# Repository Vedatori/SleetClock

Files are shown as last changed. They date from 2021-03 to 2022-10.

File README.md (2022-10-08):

# SleetClock [cz]
SleetClock je otevřená platforma chytré meteostanice vyvinutá jako projekt pro výuku elektroniky a programování. Ve fázi návrhu byl kladen důraz na jednoduchou a levnou výrobu s vysokou užitnou hodnotou výsledného výrobku v každé domácnosti.

SleetClock byl vyvinut jako hlavní výrobek letního technického tábora 2019 v Chotěborkách pořádaným spolkem Vědátoři.
Do vývojového týmu patří Martin Ptáček, Martin Coufal, Marek Coufal a Petr Vávra z Brna.

Meteostanice je založena na 3D tištěném a laserem vyřezávaném překližkovém šasi. Srdcem výrobku je vývojový kit ESP32, který se stará o vyčítání hodnot ze senzorů, bezdrátovou komunikaci, ovládání LED symbolů počasí a o vykreslování na grafické obrazovce.

SleetClock se vyznačuje:
* Nokia 84x48 LCD grafická orbrazovka
* ESP32 MCU s podporou WiFi & Bluetooth
* Integrovaný a externí teplotní senzor
* LED indikátor počasí
* Rotační ovládací prvek, potenciometr, tlačítka a dotykové ovládání

Chceš si sestavit vlastní SleetClock? Přesuň se do sekce [návody](Manuals) a postupuj v pořadí:
1. [Elektronika](Manuals/SleetClock_electronics_cz.md)
1. [Mechanika](Manuals/SleetClock_mechanics_cz.md)
1. [Dotykový senzor](Manuals/SleetClock_touchSensor_cz.md)

## Licence
* Obsah tohoto repozitáře mimo složku *Software* je sdílen pod licencí [Attribution-NonCommercial-ShareAlike 4.0 International (CC BY-NC-SA 4.0)](https://creativecommons.org/licenses/by-nc-sa/4.0/).
* Obsah složky *Software* je sdílen pod licencí [GNU Lesser General Public License v3.0](https://www.gnu.org/licenses/lgpl-3.0.en.html).

# SleetClock [en]
SleetClock is an open-source weather station platform developed as a support for electronics and programming education. In construction emhasis was placed on easy and low-cost fabrication with a broad utilization of final product in any household.

SleetClock was developed to be the main technical project in Chotěborky 2019 Summer Camp organised by the Vědátoři society.
The developer team includes Martin Ptacek, Martin Coufal, Marek Coufal & Petr Vavra from Brno, Czech Republic.

The meteostation is based on a semi 3D-printed and plywood laser cutted chassis. SleetClock is powered by the ESP32 MCU dev kit, which takes care of reading sensor data, wireless communication, controlling the LED weather symbols and the graphical display.

The main features of SleetClock include:
* Nokia 84x48 LCD graphical display
* ESP32 MCU that enables wireless communication via WiFi & Bluetooth
* On-board & external temperature sensor
* LED weather indicator
* Rotary encoder, potentiometer, buttons & touch user control

Ready to assemble your own SleetClock? All manuals use czech descriptions so we advice using the translated version of the site. Head to section [Manuals](Manuals) and proceed in order:
1. [Electronics](Manuals/SleetClock_electronics_cz.md)
1. [Mechanics](Manuals/SleetClock_mechanics_cz.md)
1. [Touch sensor](Manuals/SleetClock_touchSensor_cz.md)

## License
* The contents of this repository excluding folder *Software* is shared under license [Attribution-NonCommercial-ShareAlike 4.0 International (CC BY-NC-SA 4.0)](https://creativecommons.org/licenses/by-nc-sa/4.0/).
* The contents of the folder *Software* is shared under license [GNU Lesser General Public License v3.0](https://www.gnu.org/licenses/lgpl-3.0.en.html).

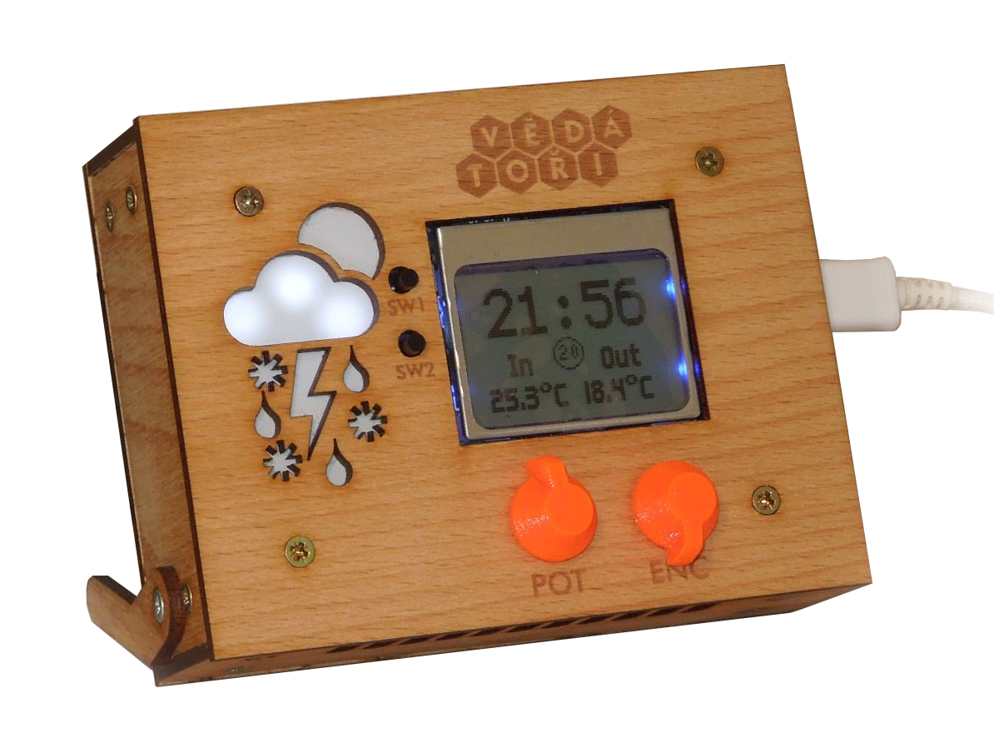
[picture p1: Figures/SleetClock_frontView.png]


Základní schéma zapojení / Schematic general:\
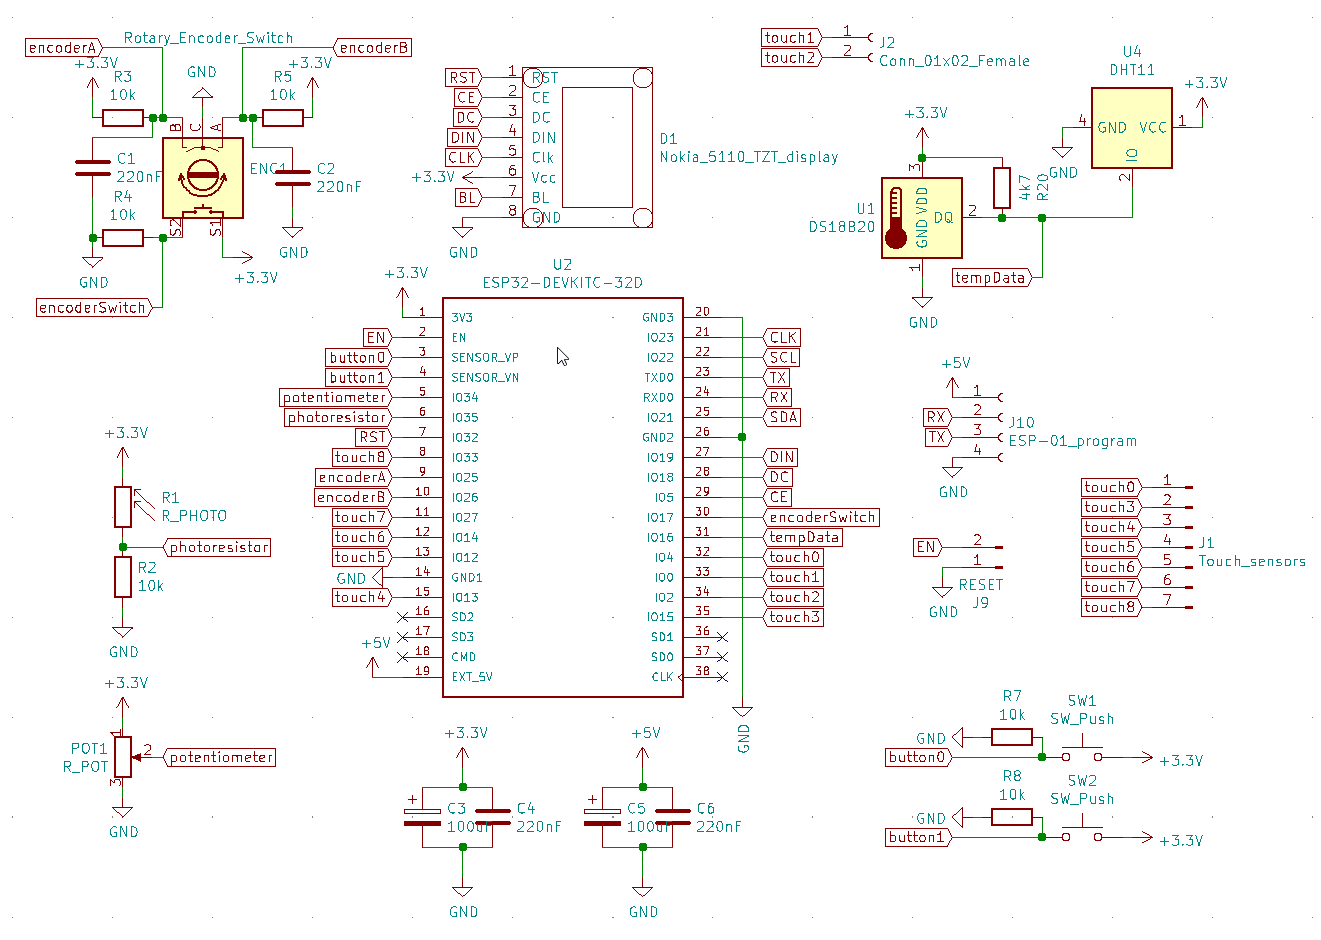
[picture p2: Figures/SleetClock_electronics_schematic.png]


Schéma zapojení LED PWM ovladače / Schematic LED PWM driver:\
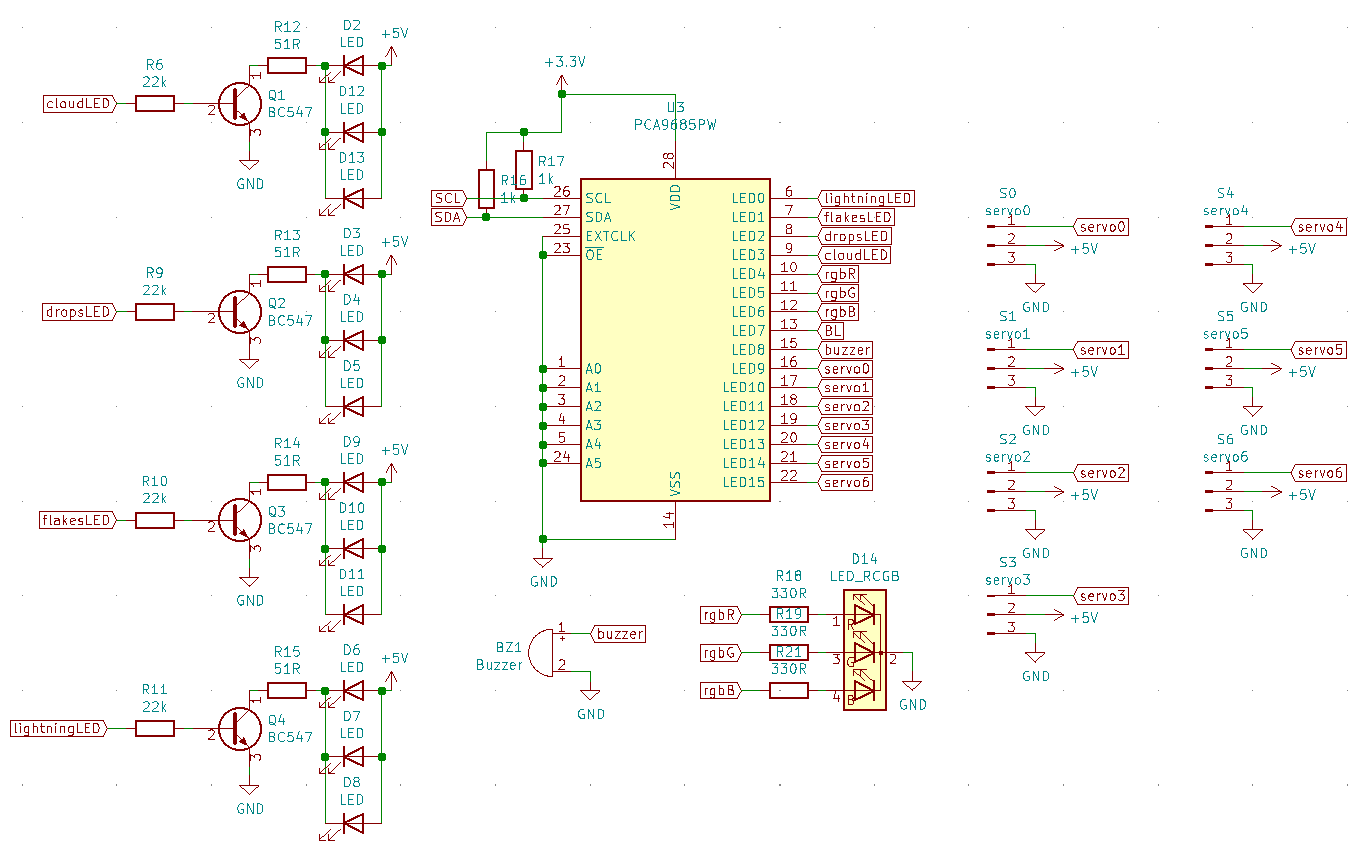
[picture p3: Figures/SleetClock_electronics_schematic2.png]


Navržená deska plošných spojů / Routed board:\
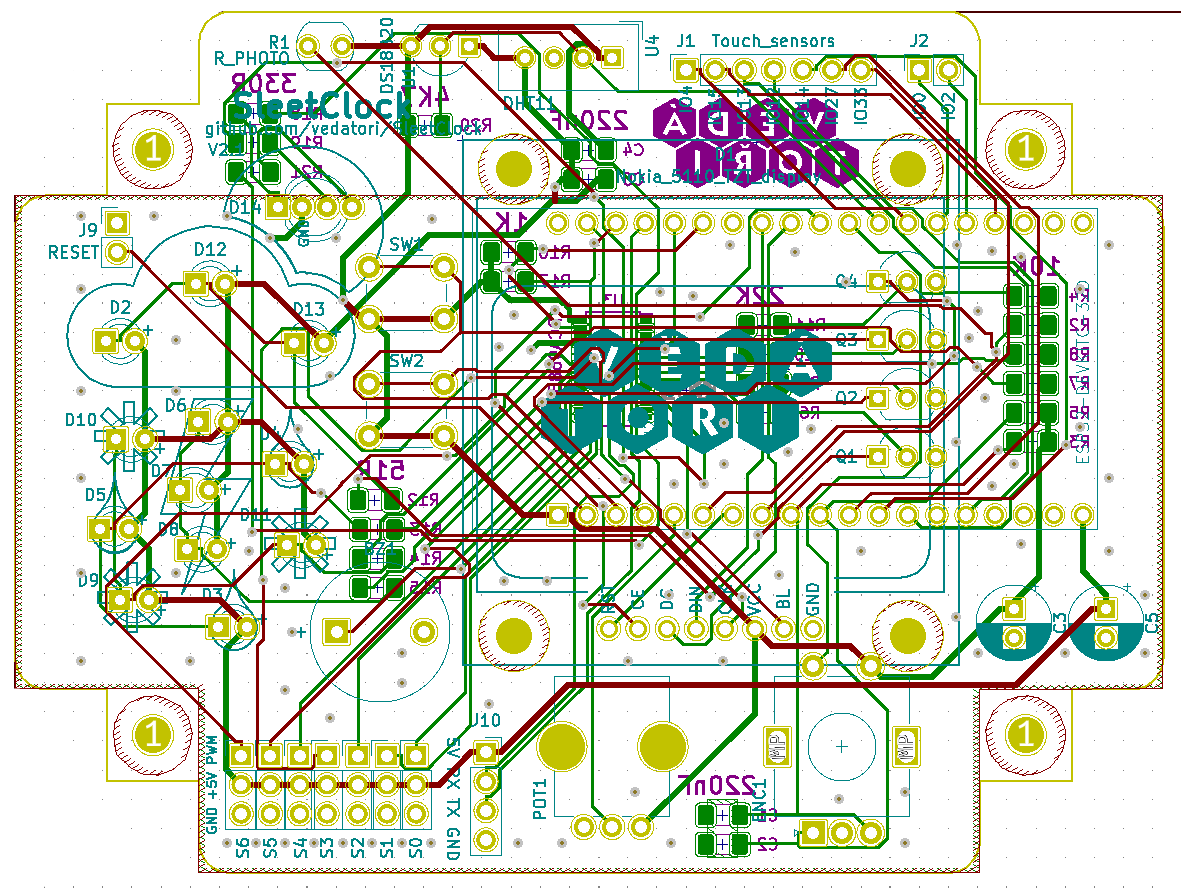
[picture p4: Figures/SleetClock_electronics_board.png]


Realizace PCB a vnitřní část šasi / Realization of PCB and inside the chassis:\
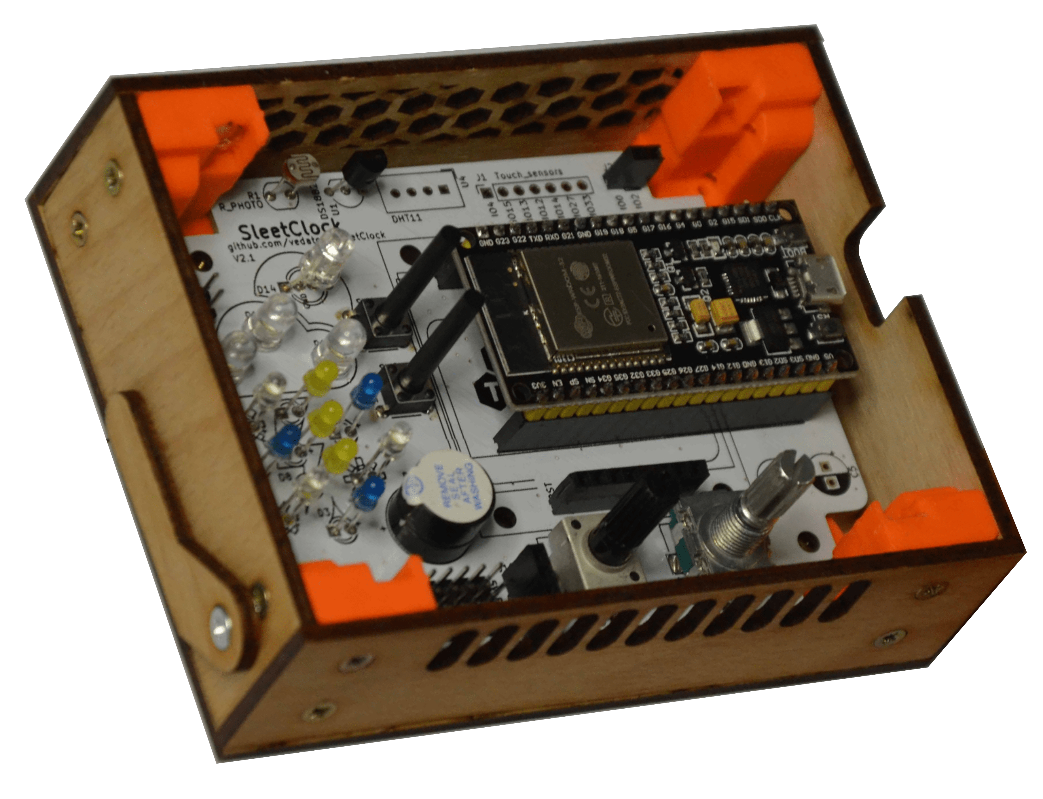
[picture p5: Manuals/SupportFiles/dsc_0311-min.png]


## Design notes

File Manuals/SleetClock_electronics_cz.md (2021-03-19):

V této kapitole je návod pro osazení desky plošných spojů pro SleetClock. V první části je osazována hlavní deska, v druhé části je popsáno osazení externího senzoru.
___
# Obsah
* [Seznam součástek](#seznamSleet)
* [Rozlomení PCB](#rozlomeni)
* [Zapájení SMD rezistorů](#smdR)
* [Zapájení SMD kondenzátorů](#smdC)
* [Zapájení kolíkových lišt](#kolik)
* [Zapájení dutinkových lišt](#dutinky)
* [Zapájení tranzistorů BC547A](#tranzistory)
* [Zapájení bzučáku](#bzucak)
* [Zapájení teplotního senzoru Dallas DS18B20](#dallas)
* [Zapájení fotorezistoru](#fotoR)
* [Zapájení 25mm tlačítek](#tlac)
* [Zapájení luminiscenčních diod (LED)](#LED)
* [Zapájení potenciometru a enkodéru](#potenc)
* [Dokončení vývojové desky](#finish)
___

## Seznam součástek
+ Vyfrézovaná PCB (Printed Circuit Board - deska plošných spojů)
+ PCA9685
+ SMD Rezistory vel. 1206 (před závorkou je uvedena hodnota, v závorce kódové označení na rezistoru)
    + 4x 51 Ω (510)
    + 3x 330 Ω (331)
    + 2x 1 KΩ (102)
    + 1x 4,7 KΩ (472)
    + 6x 10 KΩ (103)
    + 4x 22 KΩ (223)
+ 4x SMD kondenzátor 220 nF (bez popisku), vel. 1206
+ Teplotní senzor DS18B20
+ Fotorezistor
+ Kolíkové lišty
+ Dutinkové lišty
+ LED
    + RGB se společnou katodou (nejdelší nožička)
    + 3x 5 mm studená bílá
    + 3x 3 mm studená bílá
    + 3x 3 mm modrá
    + 3x 3 mm žlutá
+ Bzučák
+ 2x tlačítko 25 mm
+ 4x tranzistor BC547A
+ Potenciometr 10 KΩ s hřídelí 18mm
+ Rotační enkodér
+ ESP32 devkit
+ Nokia 5110 display
+ Jumper
+ 4x šroub M3x20 s půlkulatou hlavou
+ 8x matka M3
+ 3D tištěný tepelný štít

Součástky na zapájení do PCB můžete vidět na následujícím obrázku:
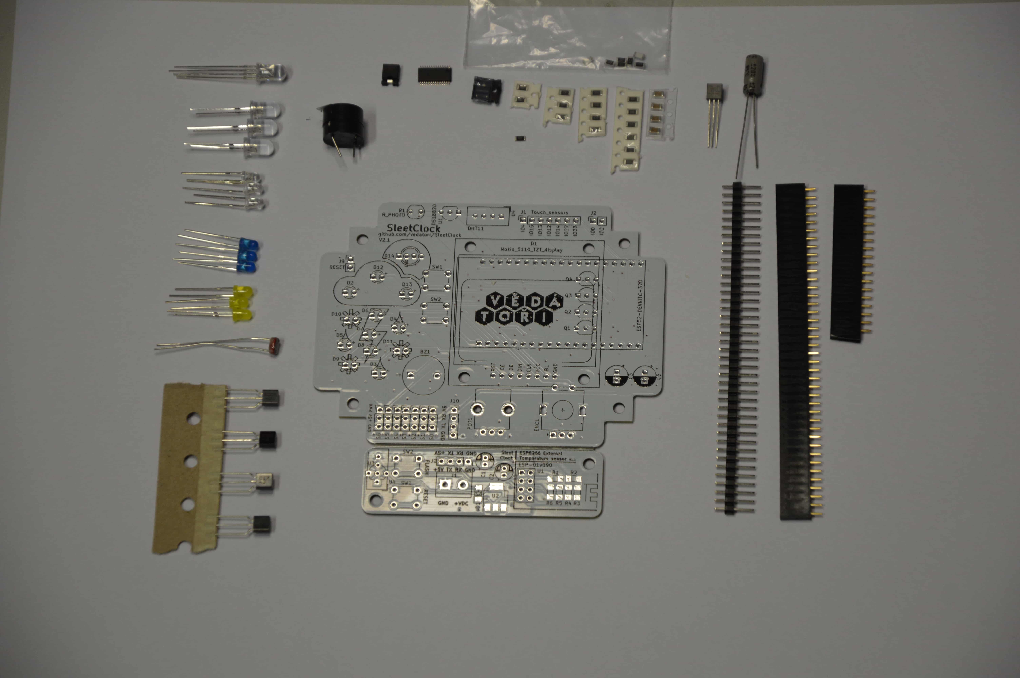
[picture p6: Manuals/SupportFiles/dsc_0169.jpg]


## Rozlomení PCB
1. Na jednom PCB je umístěna jak hlavní deska, tak i deska externího senzoru. PCB je frézovaná, rozlomte ho na dvě části podle drážky. To by mělo jít bez použití nadměrné síly.

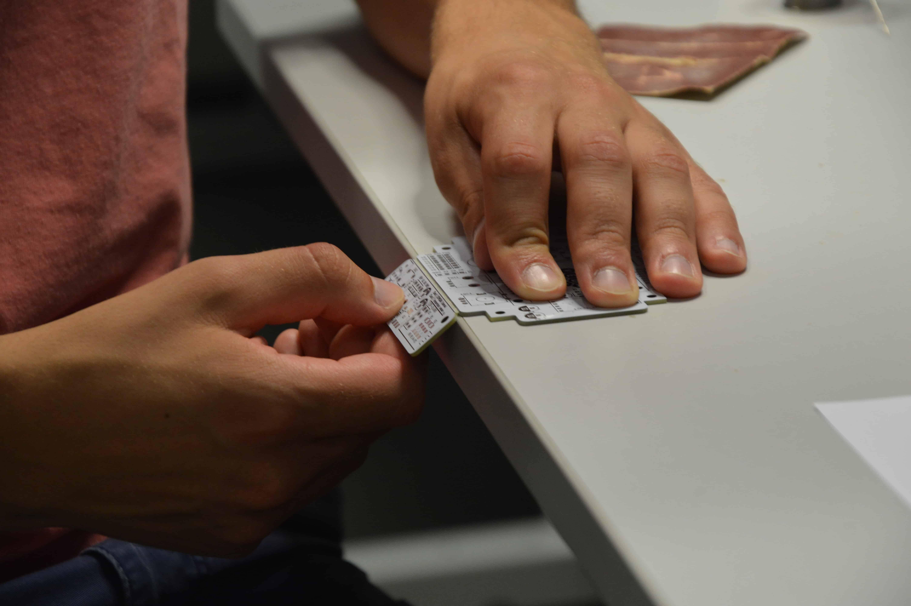
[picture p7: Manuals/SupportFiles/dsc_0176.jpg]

2. Po rozlomení opracujte nově vzniklé hrany smirkovým papírem.
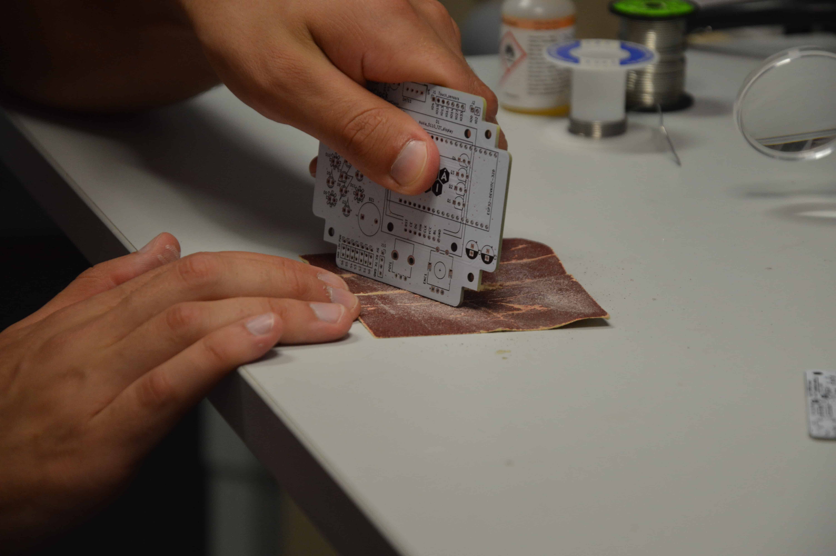
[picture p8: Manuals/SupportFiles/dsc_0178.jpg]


#### Pohled na hlavní PCB
Toto je pohled na PCB zepředu. Z této strany se SleetClock běžně nepájí! Existuje však jedna výjimka, ale o té se v návodu dočtete. :)
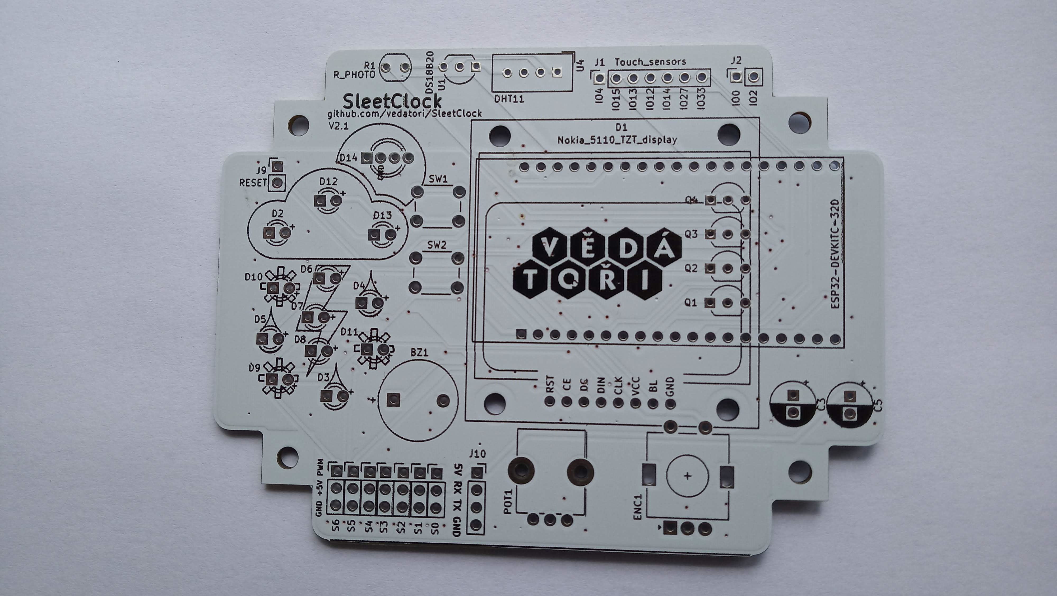
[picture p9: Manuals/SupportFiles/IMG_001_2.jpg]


Takto vypadá SleetClock zezadu. Z této strany budete pájet naprostou většinu součástek. Jako malý dárek už od nás máte zapájené PCA (integrovaný obvod SOIC). :) To má tak malé rozteče vývodů, že jsme pro něj zvolili jinou techniku pájení. Jen si zkontrolujte, že tam opravdu je.
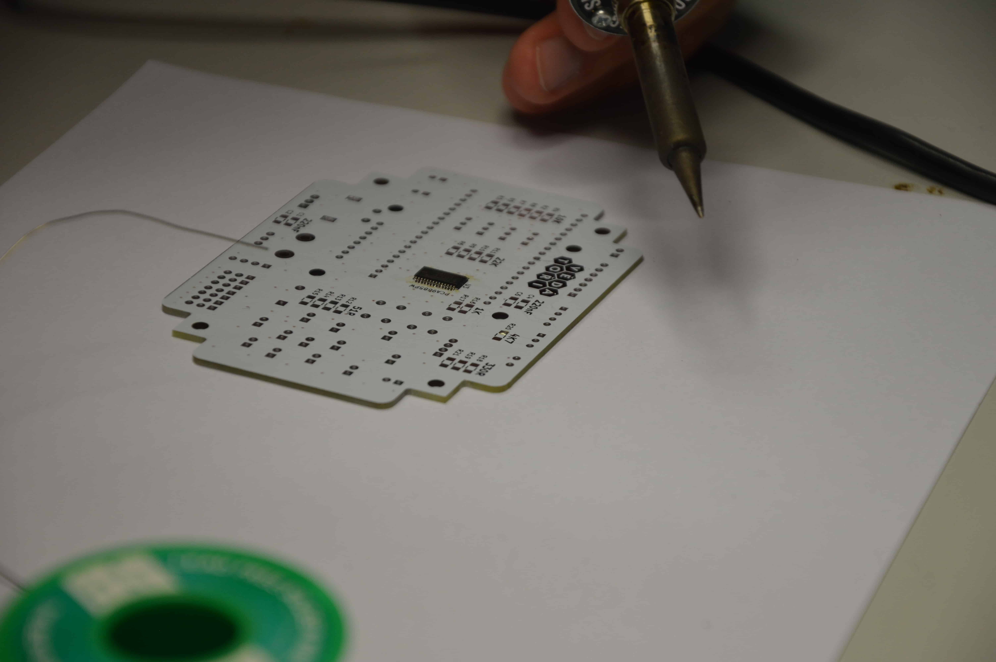
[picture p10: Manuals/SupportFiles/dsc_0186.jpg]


#### Osazení hlavní PCB
Součástky pajíme do PCB v pořadí podle 2 klíčů:
* Nejdříve nejmenší - ať neblokují místo při pájení dalších součástek
* Nejdříve teplotně nejodolnější - kdyby došlo k jejich nahřátí při dalším pájení
Tyto dvě metody nejdou vždy ruku v ruce, je tedy zvolen vhodný kompromis.

Následující součástky (SMD - Surface Mount Device) se na desku přikládají i pájí ze spodní strany (bez nápisu SleetClock).

## <a name = "smdR">Zapájení SMD rezistorů</a>
Nyní zapájejte SMD rezistory.
Jako první pájejte SMD rezistor hodnoty 4,7 KΩ. Je na něm napsáno “472”, což je myšleno jako 47*10^2. Takto jsou značeny všechny použité SMD rezistory. Tento rezistor zapájejte na místo s označením 4K7.
Nápisy na rezistorech musí směřovat nahoru, aby zůstaly čitelné. Stejně tak nesmí být nápis na rezistoru “vzhůru nohama”.    
1. Nahřejte jednu plošku pro SMD rezistor a přidejte na ni malé množství cínu.
1. Pinzetou uchopte rezistor a přiložte ho na cín, který se uchytil na plošce. Dbejte na jeho správné usazení, nesmí být posunutý a nesmí stát ve vzduchu.\  
1. Cín nahřejte páječkou. Pinzetou dolaďte umistění rezistoru, když je cín roztavený.
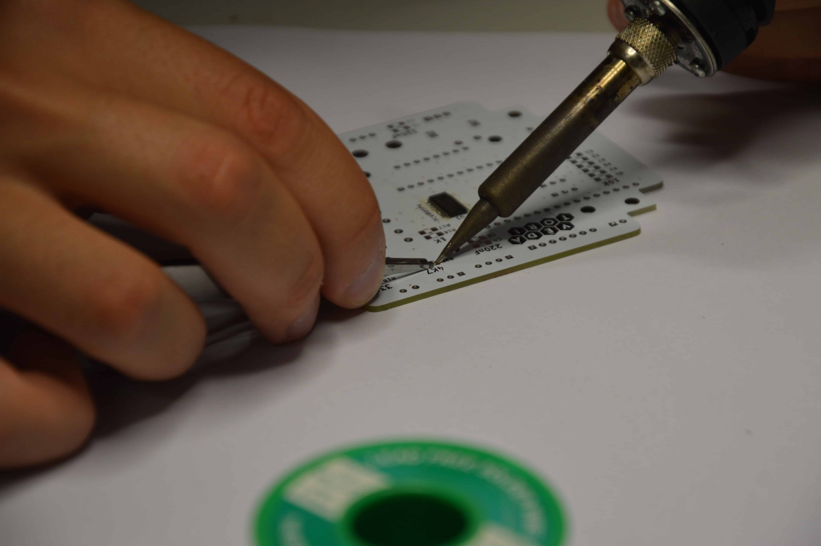
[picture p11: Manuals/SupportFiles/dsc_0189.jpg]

1. Zapájejte druhý vývod rezistoru. Nahřejte vývod a plošku a poté přidejte malé množství cínu potřebné k jejich spojení.\
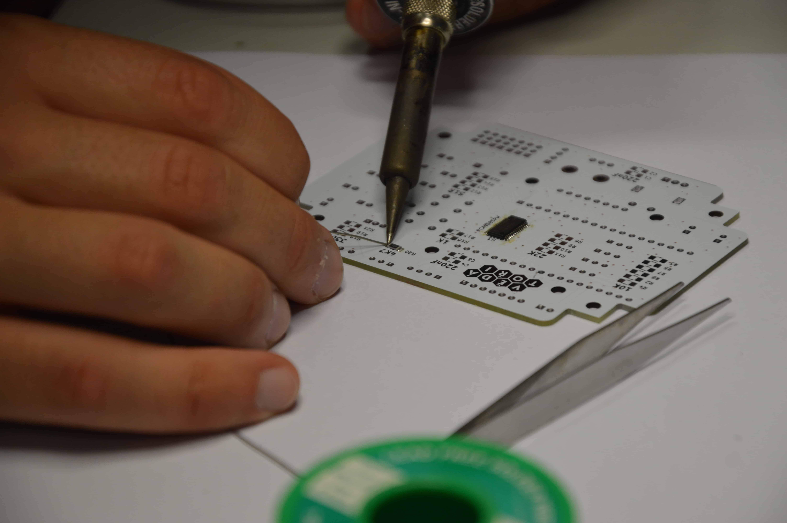
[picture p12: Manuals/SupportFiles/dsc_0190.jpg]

1. Obdobným způsobem zapájejte ostatní rezistory. Na polích s více rezistory si vždy naneste cín na všechny plošky na jedné straně a poté po jednom pinzetou přikládejte rezistory. Ty musí být vpájeny do správných míst podle popisků na plošném spoji podle následujícího rozpisu (před závorkou je uvedené označení na desce a v závorce kód rezistoru):
    + 4x 51R (510)
    + 3x 330R (331)
    + 2x 1K (102)
    + 1x 4K7 (472)
    + 6x 10K (103)
    + 4x 22K (2202)
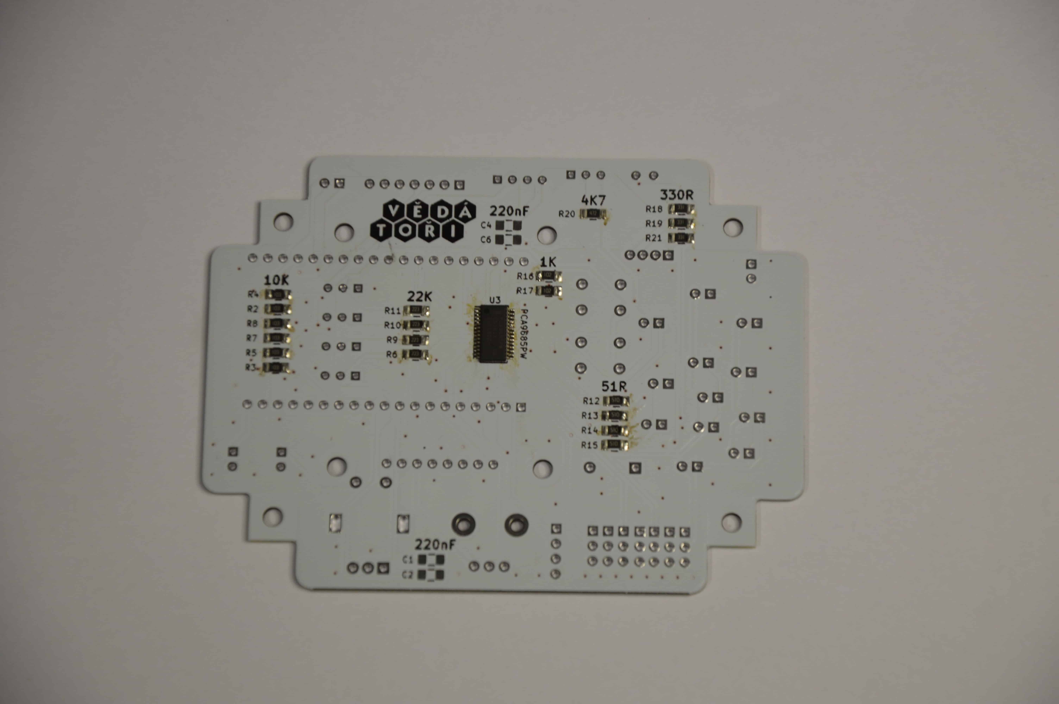
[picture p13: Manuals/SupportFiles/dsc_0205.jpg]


## <a name = "smdC">Zapájení SMD kondenzátorů</a>
SMD kondenzátory se pájí obdobným zůsobem jako SMD rezistory. Jedná se o hnědé součástky zabalené v podobné pásce. Nemají na sobě žádné označení, ale všechny čtyři mají stejně velkou kapacitu.
1. Připájejte je na místa označená 220nF.\
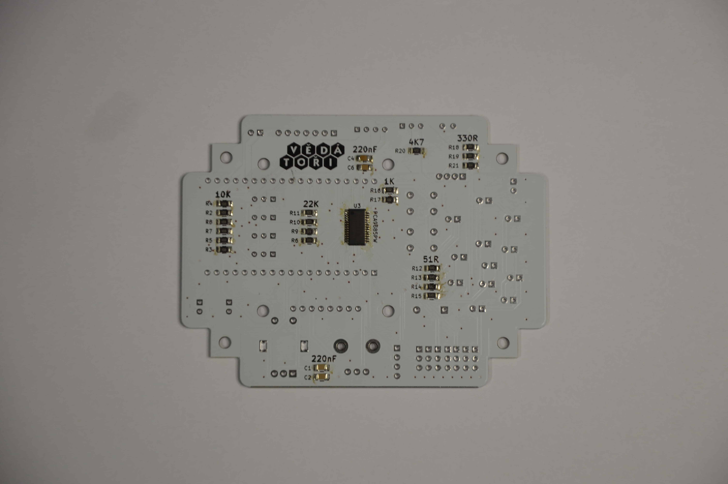
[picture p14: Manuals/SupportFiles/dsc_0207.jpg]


Následující součástky se do desky vkládají z přední strany (tam, kde je nápis SleetClock). Pájí se ale pořád ze spodní strany (bez nápisu).

## <a name = "kolik">Zapájení kolíkových lišt</a>
Kolíková lišta v její původní podobě má 40 pinů. Z ní štípacímí kleštěmi ustřihněte více částí, jedna bude mít 2 piny, další tři poté po sedmi pinech každá. Při odštípávaní kolíkových lišt dbejte na to, abyste nepoškodili plastovou část kolíkové lišty, kterou budete potřebovat.
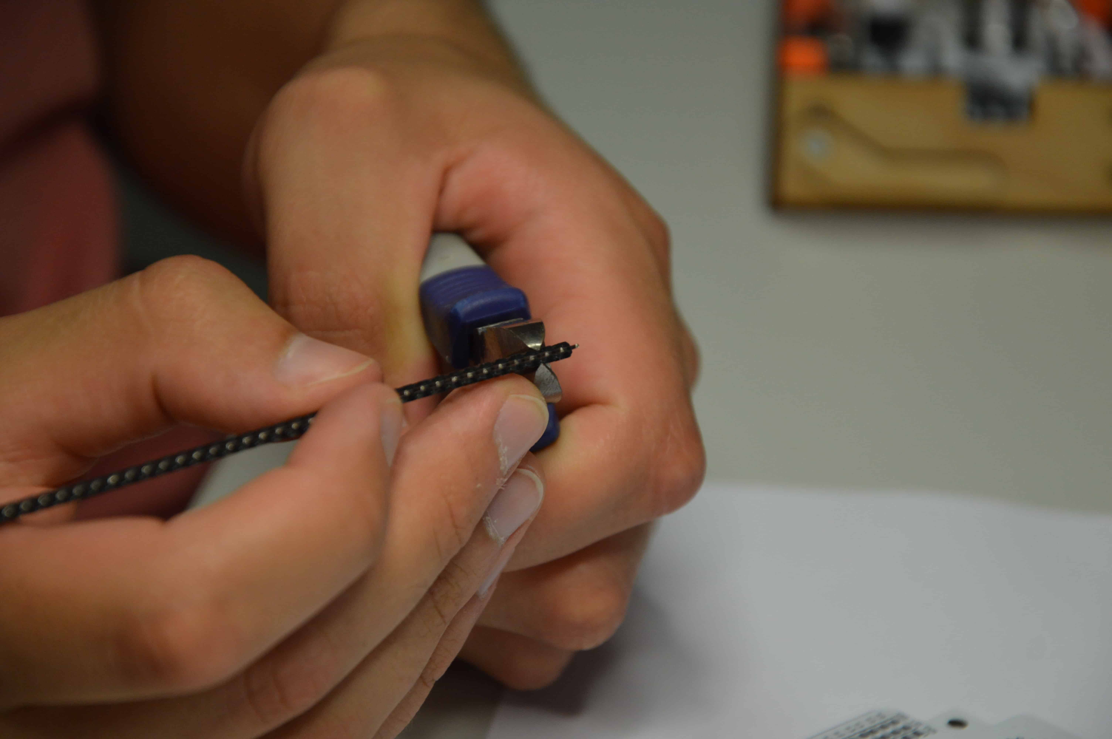
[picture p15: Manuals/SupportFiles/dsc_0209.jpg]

1. První bude zapájena 2pinová kolíková lišta, a to nad symboly počasí k nápisu RESET. Tu umístěte shora do PCB. Delší strana kolíkové lišty musí zůstat na horní straně desky.\
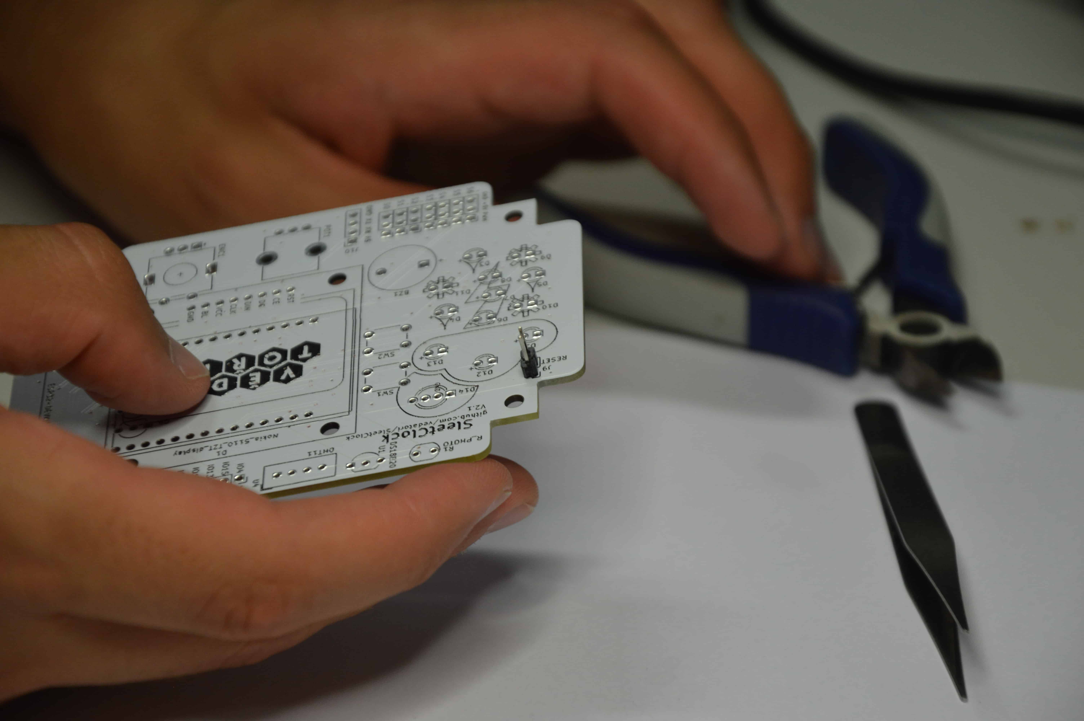
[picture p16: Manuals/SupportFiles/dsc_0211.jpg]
 
1. Ze zadní strany PCB zapájejte jeden pin. Pokud je kolíková lišta zapájená nakřivo, narovnejte ji mírným ohnutím.\
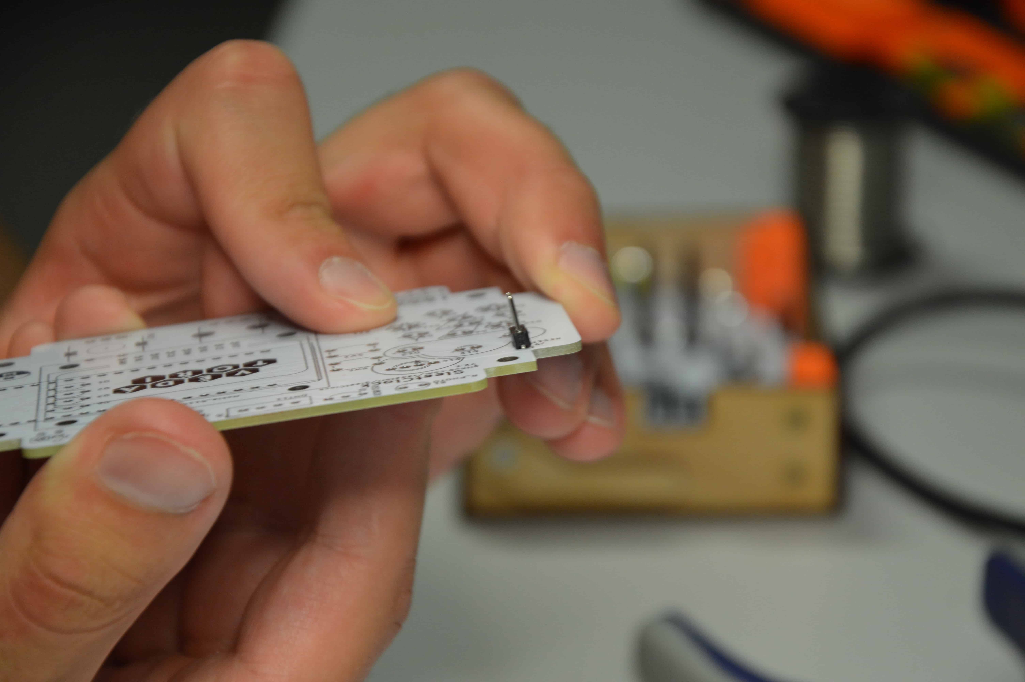
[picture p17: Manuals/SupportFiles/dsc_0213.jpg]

1. Zapájejte druhý kolík lišty.\
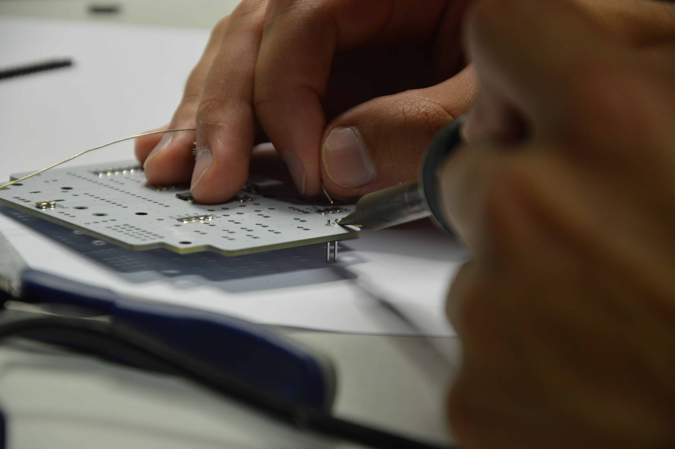
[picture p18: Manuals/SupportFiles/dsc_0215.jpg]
 
1. Obdobným způsobem zapájejte všechny 7pinové kolíkové lišty (nejdříve zapájet pouze jeden pin a poté zarovnat). Budou připájeny pod symboly počasí tam, kde je označení S0...S6.\
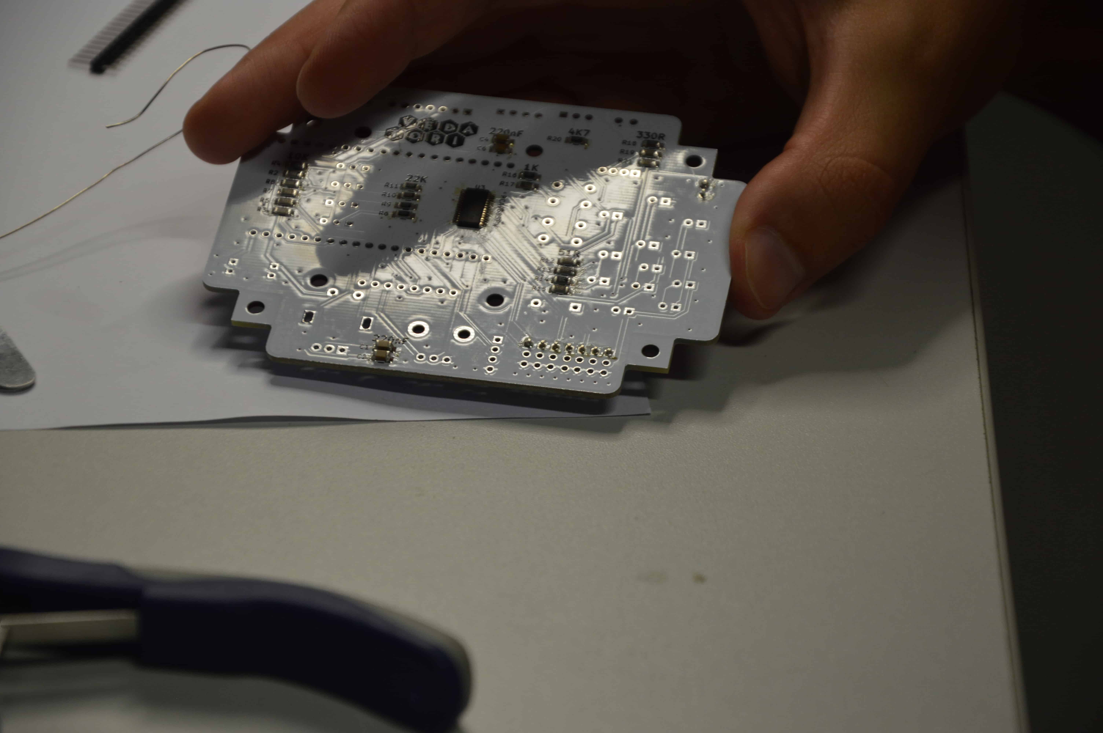
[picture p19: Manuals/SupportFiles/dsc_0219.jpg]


## <a name = "dutinky">Zapájení dutinkových lišt</a>
Dutinkové lišty mají stejně jako kolíkové v základu 40 pinů. I ty bude potřeba dělit pomocí štípacích kleští. Oproti nim je v postupu takový rozdíl, že při jejich dělení se neštípá mezi jednotlivými piny, ale odpočítá se potřebný počet pinů a odštípnutí se porvede u dalšího pinu, který se tím zničí a z lišty vypadne. Pokud tedy potřebujeme 19pinovou dutinkovou lištu, odštípneme ji až u dvacátého pinu.
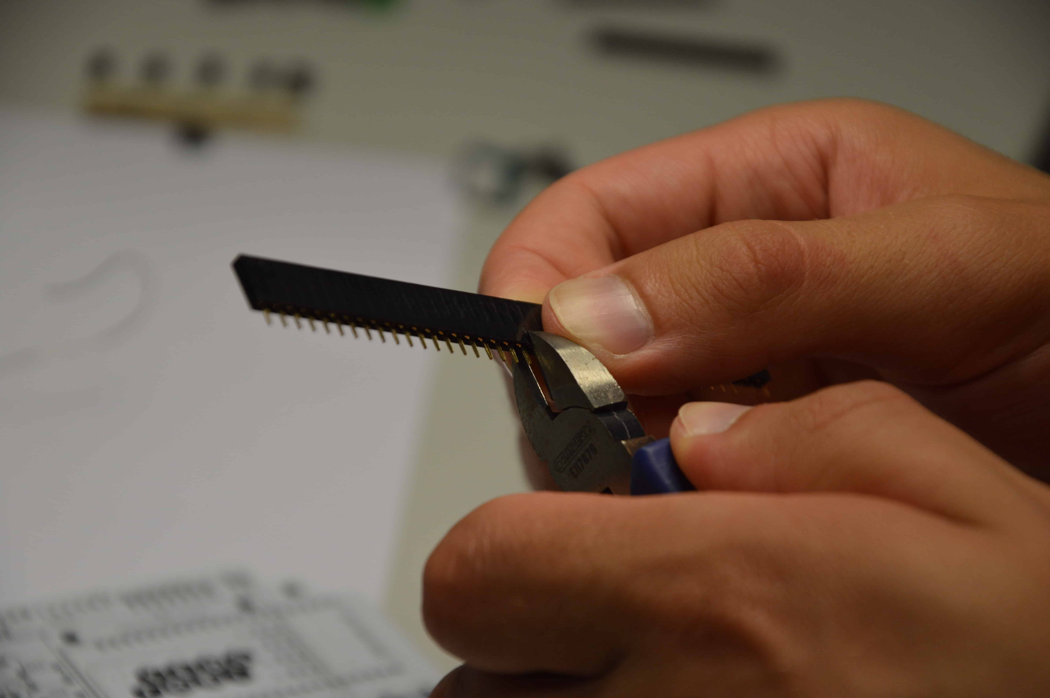
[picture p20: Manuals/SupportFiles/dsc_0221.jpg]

Po odpadlém pinu zůstane prázdné místo, to začistíme zalamovacím nožem do rovna tak, aby vypadalo stejně jako kraj dutinkové lišty odlitý v továrně.
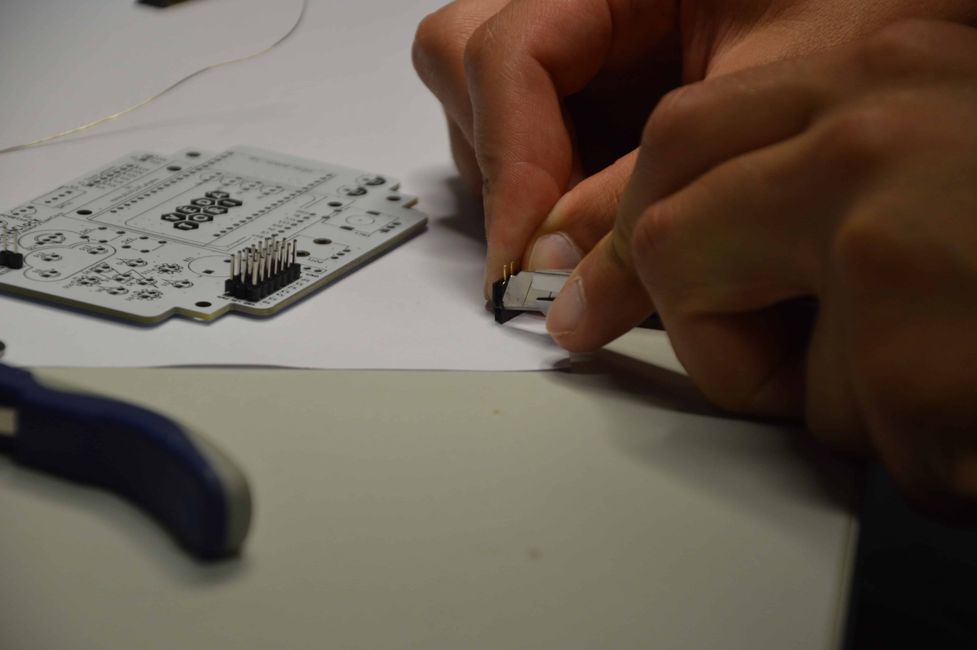
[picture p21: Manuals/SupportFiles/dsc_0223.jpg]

1. První budou zapájeny dvě 19pinové dutinkové lišty, a to do míst u velkého loga Vědátoři. Umístěte je shora do PCB. Černá část kolíkové lišty musí zůstat na horní straně desky.
1. Ze zadní strany PCB zapájejte jeden pin. Pokud je lišta zapájená nakřivo, narovnejte ji mírným ohnutím.\
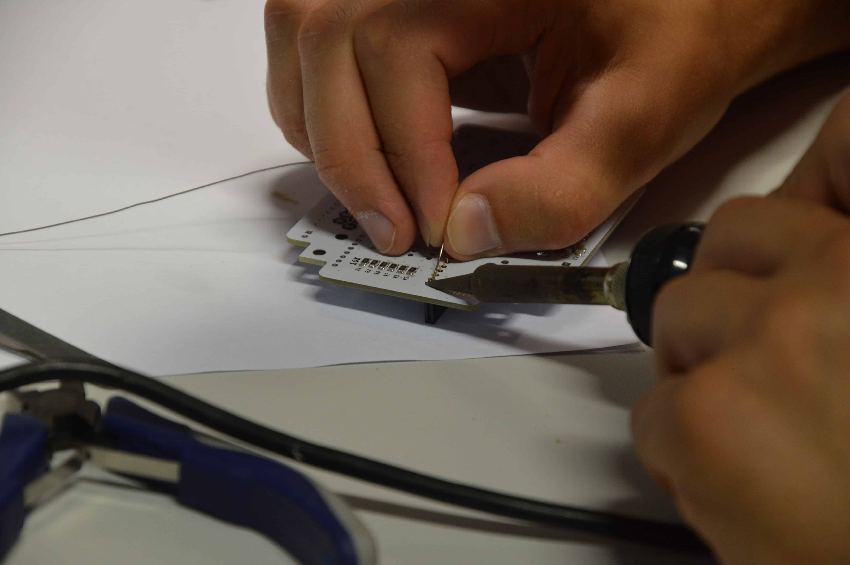
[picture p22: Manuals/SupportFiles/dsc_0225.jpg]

1. Zapájejte ostatní kolíky lišty.\
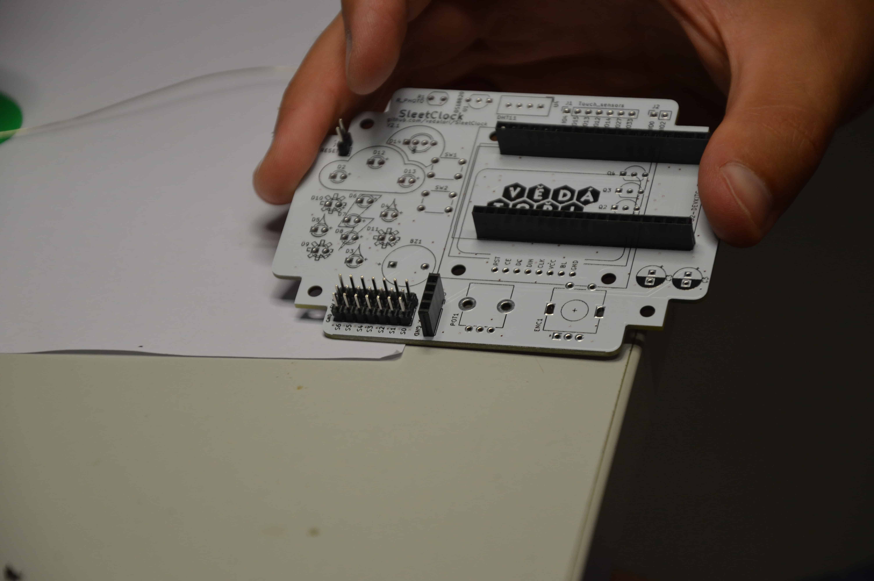
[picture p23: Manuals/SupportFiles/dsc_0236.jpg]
 
1. Obdobným způsobem vytvořte a zapájejte všechny ostatní dutinkové lišty:
    * 4pinovou k nápisu J10 vedle již zapájených kolíkových lišt
    * 8pinovou pod velké logo Vědátoři, k nápisům RST, CE, DC, DIN,...
    * 2pinovou k nápisu J2 v pravé horní části desky

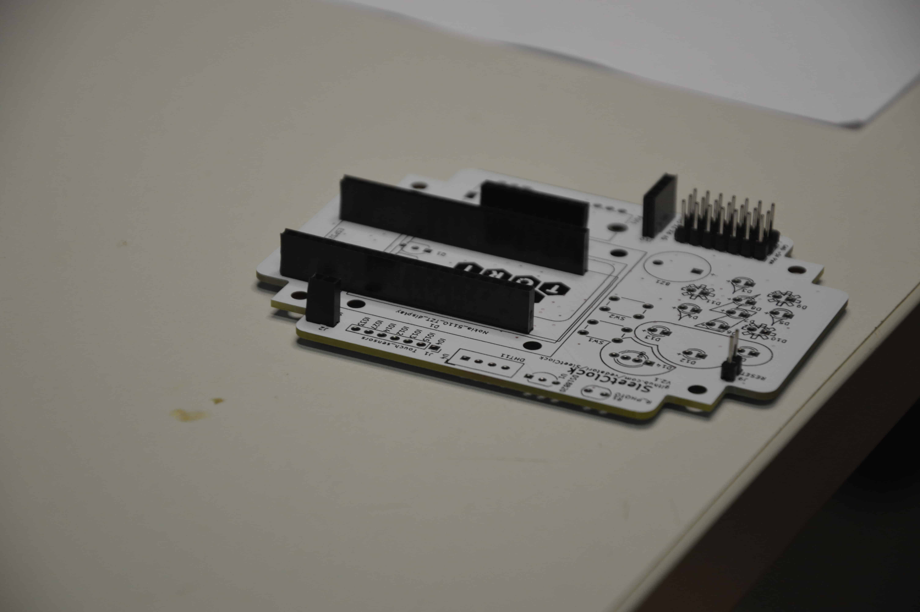
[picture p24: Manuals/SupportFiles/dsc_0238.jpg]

    
## <a name = "tranzistor">Zapájení tranzistorů BC547A</a>
Do SleetClock zapájíte čtyři tranzistory BC547A. Zkontroluje důsledně u každého, jestli má na pouzdře opravdu nápis BC547A. Stejný typ pouzdra má totiž i teplotní senzor (s nápisem DALLAS), který použijeme později. Tranzistory pájejte jedem po druhém.
1. Tranzistor umístěte shora do PCB. Orientace jeho pouzdra musí odpovídat nákresu na PCB.\
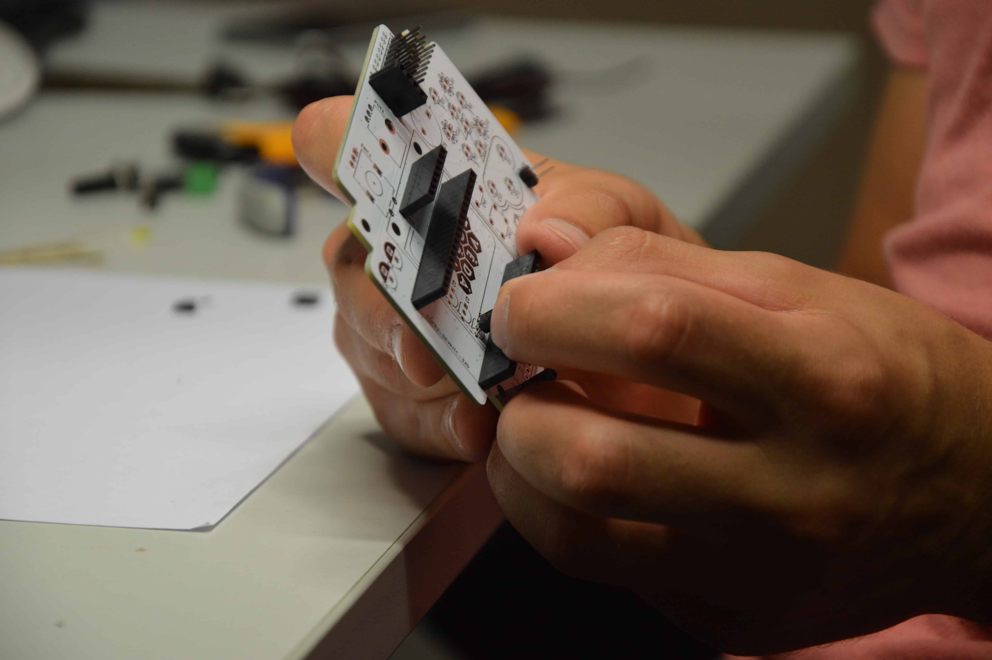
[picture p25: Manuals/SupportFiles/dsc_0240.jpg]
 
1. Krajní nožičky ohněte směrem ven.\
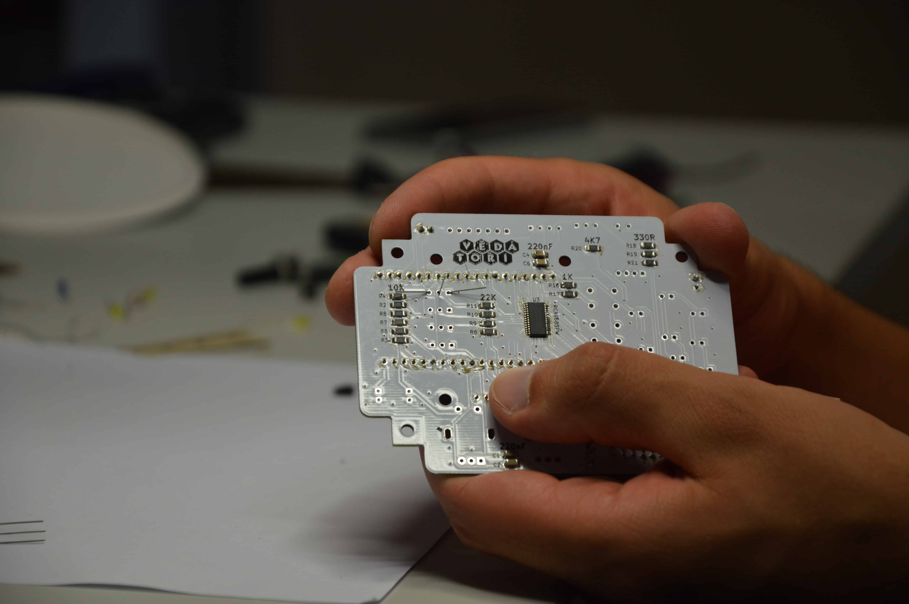
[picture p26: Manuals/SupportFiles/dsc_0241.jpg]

1. Zapájejte jednotlivé vývody tranzistoru.\
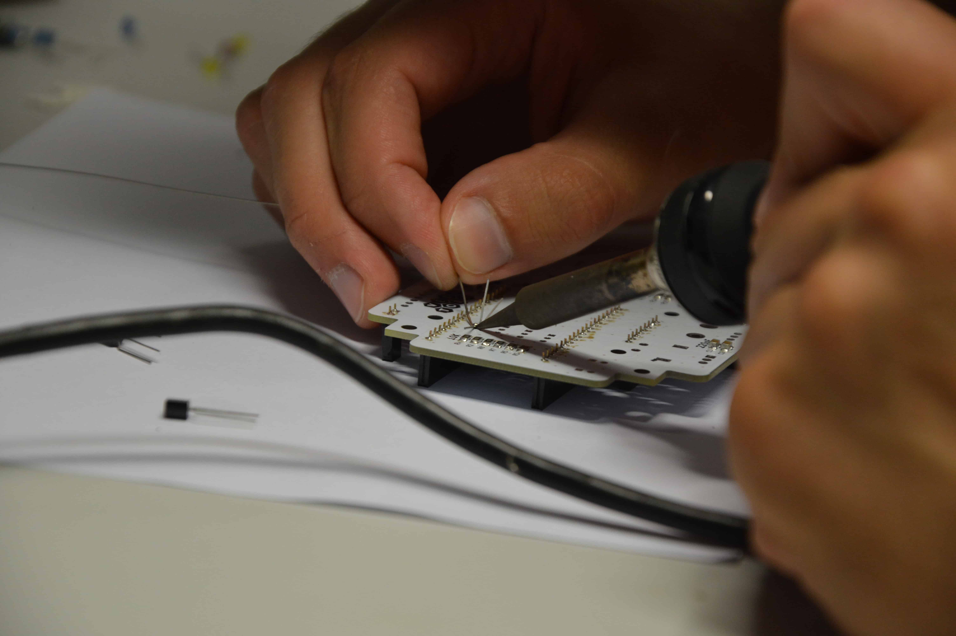
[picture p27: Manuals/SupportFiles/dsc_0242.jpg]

1. Obdobným způsobem zapájejte ostatní tranzistory.\
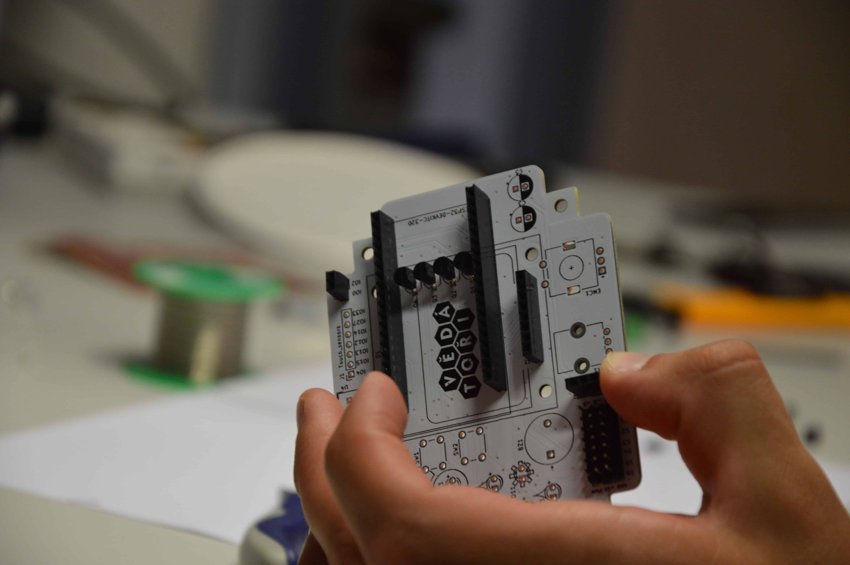
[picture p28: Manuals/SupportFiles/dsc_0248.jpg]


## <a name = "bzucak">Zapájení bzučáku</a>
Pozor na polaritu bzučáku, na desce je vývod + nalevo. Na součástce je krycí fólie, na které je + také nazančeno, tyto + musí jít k sobě.
1. Bzučák umístěte shora do DPS.\
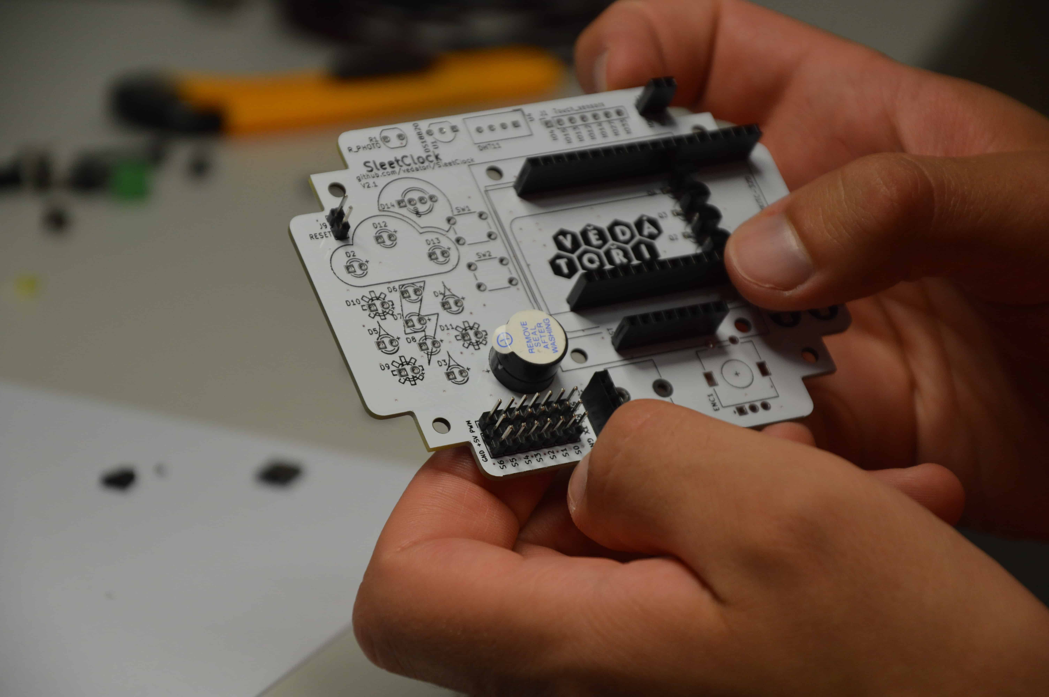
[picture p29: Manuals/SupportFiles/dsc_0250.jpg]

1. Ze spodu zapájejte.

## <a name = "dallas">Zapájení teplotního senzoru Dallas DS18B20</a>
Zkontrolujte, že na součástce je napsáno DALLAS.
1. Součástku umístěte do horní části PCB k nápisu DS18B20. Zkontrolujte, že je otočená stejně jako nákres na PCB.\

1. Zapájejte stejným způsdobem jako tranzistor.

## <a name = "fotoR">Zapájení fotorezistoru</a>
1. Fotorezistor umístěte vedle teplotního senzoru na místo označené R_PHOTO tak, aby jeh horní strana byla stejně vysoko jako dutinkové lišty. Ze spodu zahněte vývody.\

1. Otočte desku a zapájejte.\
 

## <a name = "tlac">Zapájení 25mm tlačítek</a>
Nyní zapájejte obě vysoká tlačítka. Jejich umístění je vedle symbolů počasí.
1. Pomocí plochých kleští zarovnejte vývody tlačítek.\

1. Tlačítko umístěte do PCB z přední strany.\

1. Pozor, vysoká tlačítka jsou jediná součástka, kterou je výhodnější zapájet z přední strany desky. Tlačítko zapájejte.\

1. Stejně zapájejte i druhé tlačítko.\


## <a name = "LED">Zapájení luminiscenčních diod (LED)</a>
K symbolům počasí zapájejte LED podle následujícího postupu:
1. RGB LED (se čtyřmi vývody) vložte do symbolu slunce. Nejdelší vývod umístěte k nápisu GND na desce.\

1. LED se půjde do desky vsunout až do vzdálenosti několika mm, poté na ni přestaňte tlačit a zapájejte.\

1. LED v 5mm pouzdru (stejné velikosti jako RGB LED) zasuňte až na doraz k desce do jejich míst v symbolu mraku.
1. Zezadu zahněte vývody tak, aby se LED vsunutá v desce nehýbala a zapájejte.\


Dále zapájejte 3mm (menší) žluté LED do míst v symbolu blesku, modré k symbolům kapky a bílé k symbolům vločky. LED musí být v dané výšce, to provedete následujícím způsobem:
Umístěte LED na příslušné místo do takové výšky, aby její spodní strana byla zarovnaná s horní stranou dutinkové lišty.

Ze spodní strany desky zahněte vývody.

Zapájejte jeden z vývodů.

LED narovnejte tak ,aby byla kolmá na PCB a nad svým symbolem na DPS.
Zapájejte druhý vývod.
1. Tímto způsobem zapájejte všechny 3mm LED jednu po druhé na jejich příslušná místa. Pořád dávejte pozor na jejich polaritu.\


## <a name = "potenc">Zapájení potenciometru a enkodéru</a>
1. Potenciometr umístěte na jeho místo označené POT1. Skrz PCB vsuňte všechny tři elektrické i oba velké fixační vývody součástky. Pokud je to nutné, vývody dorovnejte.\

1. Ze spodní strany PCB zapájejte oba fixační vývody i všechny elektrické.\

1. Obdobným způsobem usaďte a zapájejte rotační enkodér. Ten má dva fixační vývody a pět elektrických, ty jsou ze spodní i horní strany součástky.\


## <a name = "finish">Dokončení vývojové desky</a>
1. Zasuňte ESP32 do připravených dutinkových lišt až na doraz tak, aby microUSB konektor směřoval k pravému okraji desky.\

1. Ze zadní strany PCB zasuňte 4 šrouby M3x20 a zajistěte shora M3 maticemi.\

1. Na každý šroub našroubujte další M3 matici tak, aby nahoře zbyl asi 1 mm závitu.\


1. Nasuňte Nokia 5110 display. Jeho vývody musí zajet do dutinkové lišty, která je na ně připravena a do děr v jeho desce musí padnout připravené šrouby M3x20.\

1. Vložte 3D tištěný tepelný štít nalevo od obrazovky. Měl by zapadnout až těsně k PCB.\


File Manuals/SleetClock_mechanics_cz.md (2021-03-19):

V této kapitole je návod pro sestavení SleetClock ze základních dílů, které lze najít v OnShape. Základem pro sestavení je osazená deska plošných spojů, dále jsou třeba mechanické díly. Část dílů je určena pro tisk na 3D tiskárně, část dílů je navržena pro vyřezání z překližky laserem. Zbytek jsou běžně dostupné díly z hobby marketu.
___
# Obsah
* [Seznam součástek](#seznam)
* [Příprava překližkových dílů](#preklizka)
* [Osazení bočnice s magnety](#bocnice)
* [Kompletace krabičky](#krabicka)
* [Kompletace víka](#viko)
* [Osazení magnetů](#magnety)
* [Finalizace mechaniky](#finalizace)
___

## <a name = "seznam">Seznam součástek</a>

### 3D tištěné díly
+ 4x Bočnice
+ 4x Držák víka
+ 1x difuzor pro symboly počasí
+ 2x Krytka osky pro potenciometr a enkodér

### Desky z překližky
+ Levý bok
+ Pravý bok
+ Horní bok
+ Spodní bok
+ Dno
+ Víko
+ 2x Opěrka

### Hobby market
+ 4x Magnet
+ 6x Závitová vložka M3x5
+ 24x Vrut 2,5x10
+ 4x Šroub M3x6 mm s půlkulatou hlavou
+ 2x Šroub M3x10 mm se zapuštěnou hlavou


Obrázek zleva zobrazuje: Vrut 2,5x10, Závitovou vložku M3x5, Šroub M3x6 mm s půlkulatou hlavou, Šroub M3x10 mm se zapuštěnou hlavou

## <a name = preklizka>Příprava překližkových dílů</a>
1. Otvory pro šrouby se přizpůsobí vyštípnutím části překližky šroubovákem. Kolem každého otvoru, který je potřeba přizpůsobit, jsou vypáleny další struktury ve tvaru terče tak, aby nebyly proříznuty v celé tloušťce překližky. Malým plochým šroubovákem opatrně postupně vyštípněte jednotlivé části pomyslného terče vytvořeného kolem otvoru na překližce. Dávejte pozor, abyste nevyštípli materiál do moc velké hloubky tak, že vyštípnete všechny vrstvy překližky. Ideální je zasáhnout pouze jednu vrstvu, maximálně dvě ze tří. Vyštípnout části lze umístěním šroubováku jako na obrázku nebo tak, že šroubovák umístíte do vyřezaného otvoru a zatlačíte proti překližce v polovině její tloušťky.\

1. Všechny dřevěné díly opracujte smirkem hrubosti P400 až P800. Pokud na dílu nejsou žádné viditelné ani nahmatatelné nečistoty, stačí jen jednou jemně přejet smirkem.\

1. Takto připravené dřevěné díly nalakujte lakem ve spreji.\

## <a name = bocnice>Osazení bočnice s magnety</a>
K tomuto kroku jsou třeba 4 bočnice, 6 závitových vložek, z nástrojů pak pájka a ploché kleštičky. Bočnice nejsou všechny stejné, otvor na závitovou vložku směřuje doleva nebo doprava. Potřebovat budete od každého typu dvě. Pozor! Závitové vložky mají jednu stranu zkosenou. Zkosená strana musí po vložení závitové vložky vyčnívat ven, lépe navede šroub při zašroubování.

1. Nachystejte si díly podle obrázku a rozehřejte pájku na 300 °C.\

1. Vezměte do kleštiček závit, do závitu přiložte horkou pájku a závit rozehřejte.\

1. Závit postupně vsouvejte do bočnice.\

1. Odložte pájku do stojánku. Bočnici chytněte za plastovou část a závit jemně zalisujte např. o hranu stolu.\

1. Tento postup opakujte pro zbylé 3 bočnice.\
        
1. Bočnice vystavte na stůl dle obrázku. Pro spodní 2 bočnice stejným postupem z předešlých bodů "vpalte" boční závity. Pozor v tomto případě se bočnice mohou snadno převrhnout.\

1. Nezpomeňte opět jemně zalisovat o stůl.\


## <a name = krabicka>Kompletace krabičky</a>
K tomuto kroku budou třeba všechny doposud vyrobené díly. Z nástrojů křížový šroubovák PH1 nebo PZ1, šroubky (*výčet šroubků*), lihový fix a lepidlo.

1. Opracované díly si vyskládejte na stůl podle obrázku. Označené bočnice mají z boku vpálený závit.\

1. Všechny bočnice postupně přišroubujte ke dnu, šrouby nedotahujte doplna.\

1. Připevněte spodní díl do bočnic, šrouby opět nedotahujte.\

1. Obdobně horní díl. Zkontroulujte, že máte závity vpálené na stejných místech jako na obrázku, a že máte stejně rozmístěné děrování.\

1. Připevněte boční díly. Opět zkontrolujte, že máte vše ve shodě s obrázkem.\

1. Vycentrujte krabičku, aby seděla do pravých úhlů a postupně jemně dotáhněte.\



## <a name = viko>Kompletace víka</a>

1. Nyní přišroubujte držáky magnetů k víku. Směr držáků dodržte stejně jako na obrázku.\


1. Výsledkem by měl být stav z následujích 2 obrázků.\


1. Kolem výřezů, které naznačují ikony počasí naneste lepidlo.\

1. Přebytečné lepidlo odstraňte kusem papíru.\

1. Nanesenou vrstvu lepidla nechte několik minut odvětrat.\

1. Přilepte díl s difuzorem.\

1. Zkontrolujte přesnost centrování proti světlu. Lepidlo by ještě nemělo být zaschlé a s difuzorem by mělo být možné pohybovat po desce. Pokud to je možné, s difuzorem pohybujte klouzáním po desce, již od desky neodlepujte.\


## <a name = magnety>Osazení magnetů</a>

1. Magnety rozdělte na dvojice. Lihovým fixem označte tečkou vnější strany dvojice magnetů. Strany, které mají vůči sobě kontakt ponechte prázdné.\

1. Naneste lepidlo do prostoru pro magnety na bočnicích krabičky.\

1. Vložte magnet tak, abyste neviděli tečky, které jste vytvořili v předešlém kroku. Odstraňte papírem přebytečné lepidlo.\

1. Postup opakujete pro víko. **Krabičku nezavírejte minimálně po dobu jedné hodiny.** Hrozí totiž trvalé slepení plastových dílů nebo posunutí magnetů.\


## <a name = finalizace>Finalizace mechaniky</a>

1. Pomocí šroubů M3x10 se zapuštěnou hlavou přišroubujte oba stojánky. Hlavičky šroubů musí být zapuštěny do připravených otvorů ve stojáncích.\


1. Přišroubujte zkompletovanou desku PCB pomocí 4 šroubů M3x6 s půlkulatou hlavou.\

1. Nasaďte překližkové víko s magnety na krabičku.\

1. Na vyčnívající osky potenciometru a enkodéru nasuňte tištěné krytky.\


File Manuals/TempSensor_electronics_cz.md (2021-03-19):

V této kapitole je návod pro osazení desky plošných spojů pro SleetClock.
___
# Obsah
* [Seznam součástek](#seznam)
* [Pohled na PCB externího senzoru](#pohled)
* [Osazení rezistorů](#R)
* [Osazení schottkyho diody](#shottky)
* [Osazení stabilizátoru AMS1117](#stabil)
* [Osazení tlačítek](#tlac)
* [Osazení dutinkové lišty 4x2](#dutinka)
* [Osazení teplotního senzoru DALLAS DS18B20](#dallas)
* [Osazení dutinkové lišty](#dutinka2)
* [Osazení svorkovnice](#svorkovnice)
* [Osazení kondenzátoru](#C)
* [Lakování desky pasivačním lakem](#lakovani)
* [Vložení ESP01](#vlozeni)
* [Výroba propojovacího kabelu](#propojka)
___

## <a name = "seznam">Seznam součástek</a>
+ Druhá část PCB
+ SMD Rezistory vel. 1206 (před závorkou je uvedena hodnota, v závorce kódové označení na rezistoru)
    + 2x 330 Ω (331)
    + 4x 4,7 KΩ (472)
+ Schottkyho dioda LM5819
+ 2x teplotní senzor DS18B20
+ 2x mikrotlačítko
+ Dutinková lišta
+ Dutinková lišta 4x2
+ Svorkovnice DC
+ Kondenzátor 100 μF/min. 5 V
+ Sabilizátor AMS1117
+ ESP01

Součástky můžete vidět na následujícím obrázku.


#### <a name = "pohled">Pohled na PCB externího senzoru</a>
Toto je pohled na PCB zepředu.


Takto vypadá PCB zezadu.
 

## <a name = "R">Osazení rezistorů</a>
SMD rezistory pájejte stejným způsobem jako na hlavní desce.
1. Na pozice označené R1 a R2 připájejte rezistory 330 Ω, ozn. 331.\
 
1. Na pozice označené R4 až R26 připájejte rezistory 4,7 KΩ, ozn. 472.\


## <a name = "shottky">Osazení schottkyho diody</a>
1. Schottkyho diodu umístěte na pozici D1 tak, že pruh na diodě směřuje stejným směrem, jakým ukazuje šipka na DPS.\
1. Diodu zapájejte stejným způsobem jako SMD rezistory.\

    
## <a name = "stabil">Osazení stabilizátoru AMS1117</a>
Stabilizátor je na desce umístěn vedle diody D1. Footprint obsahuje čtyři vývody.
1. Plošku pro velký vývod (je určený pro případné chlazení) nahřejte a naneste na ni cín.\
1. Uchopte stabilizátor do pinzety a umístěte ho na jeho místo na desce. Neustále ho přidržuje pinzetou a roztavte cín nanesený na plošce pro chlazení. Na tuto plošku odpovídající vývod stabilizátoru připájejte.\

1. Připájejte tři další vývody stabilizátoru.\


## <a name = "tlac">Osazení tlačítek</a>
1. Z horní strany desky umístěte tlačítka a jejich vývody prostrčte deskou. Tlačítka by měla v desce sama držet.\
1. Ze spodní strany tlačítka zapájejte.\


## <a name = "dutinka">Osazení dutinkové lišty 4x2</a>
Tuto dutinkovou lištu nemusíte narozdíl od předchozích zkracovat. Je vyrobena na míru pro externí senzor, obsahuje dvě řady po čtyřech pinech.
1. Dutinkovou lištu nasuňte z horní strany DPS a ze zadní strany zapájejte.\


## <a name = "dallas">Osazení teplotního senzoru DALLAS DS18B20</a>
1. Zkontrolujte, že součástka, kterou se chystáte osadit, je teplotní senzor DALLAS (nesmí na ní být napsáno BC547).\
1. Teplotní senzor umístěte do levé části desky a zkontrolujte, zda-li odpovídá nákresu na DPS.\

1. Horní stranu senzoru umístěte do výšky dutinkové lišty.\
1. Zapájejte stejným způsobem jako u hlavní desky.\


## <a name = "dutinka2">Osazení dutinkové lišty</a>
1. Stejným způsobem jako u hlavní desky vyrobte dutinkovou lištu se 4 piny.\
1. Zapájejte na místo s popisky GND, RX, TX, 5V.\

## <a name = "svorkovnice">Osazení svorkovnice</a>
1. Nasaďte svorkovnici z přední strany desky a ze zadní napájejte.
Svorkovnice musí být úplně doražená k DPS.\


## <a name = "C">Osazení kondenzátoru</a>
1. Nasaďte elektrolytický kondenzátor z přední strany desky a ze zadní napájejte.\


## <a name = "lakovani">Lakování desky pasivačním lakem</a>
1. Osazenou DPS nalakujte pasivačním lakem.\

## <a name = "vlozeni">Vložení ESP01</a>
1. Do připravené svorkovnice 4x2 vložte ESP01.\


## <a name = "propojka">Výroba propojovacího kabelu</a>
1. Odizolujte všechny konce napájecího kabelu v délce asi 7 mm.\

1. Zacínujte všechna lanka na koncích drátu.\

Pokud není cínování rovnoměrné, cín stáhněte ke konci odizolovaného kabelu do kuličky a poté ji z drátu odstřihněte kleštěmi.\

1. Na jednom konci napájejte oba vodiče do USB konektoru. Nejdříve naneste malé množství cínu do krajních kontaktů konektoru.\

Poté připájejte kabely tak, aby drát s červeným pruhem směřoval k pravé hraně konektoru, když se na něj díváte směrem od pájecích plošek (a část konektoru, která se zasunuje do nabíječky směřuje směrem od vás). Správnost zapojení kabelu ověřte na obrázku.\

1. Nasuňte konektor do jeho plastového krytu a jemně ho stiskněte, aby se uzavřel.\

1. Druhý konec kabelu upevněte ve svorkovnici na desce externího senzoru. Dbejte na to, aby drát s červeným pruhem byl upnutý ve svorce +VDC.\


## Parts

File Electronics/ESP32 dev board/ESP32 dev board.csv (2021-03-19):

Source: | C:\Users\marou\Desktop\Chotěborky\SleetClock\Electronics\ESP32 dev board\ESP32 dev board.sch
Date: | 12.05.2019 17:58:04
Tool: | Eeschema (5.1.0)-1
Generator: | C:\Program Files\KiCad\bin\scripting\plugins/bom_csv_grouped_by_value.py
Component Count: | 68
Individual Components:
Item | Qty | Reference(s) | Value | LibPart | Footprint | Datasheet | Pole4 | Pole5 | Pole6 | Pole7 | Pole8
 |  | BZ1 | Buzzer | Device:Buzzer | Buzzer_Beeper:Buzzer_12x9.5RM7.6 | ~
 |  | C1 | 220nF | Device:C | Capacitor_SMD:C_1206_3216Metric_Pad1.42x1.75mm_HandSolder | ~
 |  | C2 | 220nF | Device:C | Capacitor_SMD:C_1206_3216Metric_Pad1.42x1.75mm_HandSolder | ~
 |  | C3 | 100uF | Device:CP | Capacitor_THT:CP_Radial_D6.3mm_P2.50mm | ~
 |  | C4 | 220nF | Device:C | Capacitor_SMD:C_1206_3216Metric_Pad1.42x1.75mm_HandSolder | ~
 |  | C5 | 100uF | Device:CP | Capacitor_THT:CP_Radial_D6.3mm_P2.50mm | ~
 |  | C6 | 220nF | Device:C | Capacitor_SMD:C_1206_3216Metric_Pad1.42x1.75mm_HandSolder | ~
 |  | D1 | Nokia_5110_display | Nokia_5110:Nokia_5110_display | Nokia 5110 display:Nokia_5110_display
 |  | D2 | LED | Device:LED | LED_THT:LED_D3.0mm | ~
 |  | D3 | LED | Device:LED | LED_THT:LED_D3.0mm | ~
 |  | D4 | LED | Device:LED | LED_THT:LED_D3.0mm | ~
 |  | D5 | LED | Device:LED | LED_THT:LED_D3.0mm | ~
 |  | D6 | LED | Device:LED | LED_THT:LED_D3.0mm | ~
 |  | D7 | LED | Device:LED | LED_THT:LED_D3.0mm | ~
 |  | D8 | LED | Device:LED | LED_THT:LED_D3.0mm | ~
 |  | D9 | LED | Device:LED | LED_THT:LED_D3.0mm | ~
 |  | D10 | LED | Device:LED | LED_THT:LED_D3.0mm | ~
 |  | D11 | LED | Device:LED | LED_THT:LED_D3.0mm | ~
 |  | D12 | LED | Device:LED | LED_THT:LED_D3.0mm | ~
 |  | D13 | LED | Device:LED | LED_THT:LED_D3.0mm | ~
 |  | D14 | LED_RCGB | Device:LED_RCGB | LED_THT:LED_D5.0mm-4_RGB_Wide_Pins | ~
 |  | ENC1 | Rotary_Encoder_Switch | Device:Rotary_Encoder_Switch | Rotary_Encoder:RotaryEncoder_Alps_EC11E-Switch_Vertical_H20mm | ~
 |  | H1 | MountingHole | Mechanical:MountingHole | MountingHole:MountingHole_3.2mm_M3 | ~
 |  | H2 | MountingHole | Mechanical:MountingHole | MountingHole:MountingHole_3.2mm_M3 | ~
 |  | H3 | MountingHole | Mechanical:MountingHole | MountingHole:MountingHole_3.2mm_M3 | ~
 |  | H4 | MountingHole | Mechanical:MountingHole | MountingHole:MountingHole_3.2mm_M3 | ~
 |  | J1 | Conn_01x09_Female | Connector:Conn_01x09_Female | Connector_PinSocket_2.54mm:PinSocket_1x09_P2.54mm_Vertical | ~
 |  | J2 | Conn_01x03_Male | Connector:Conn_01x03_Male | Connector_PinHeader_2.54mm:PinHeader_1x03_P2.54mm_Vertical | ~
 |  | J3 | Conn_01x03_Male | Connector:Conn_01x03_Male | Connector_PinHeader_2.54mm:PinHeader_1x03_P2.54mm_Vertical | ~
 |  | J4 | Conn_01x03_Male | Connector:Conn_01x03_Male | Connector_PinHeader_2.54mm:PinHeader_1x03_P2.54mm_Vertical | ~
 |  | J5 | Conn_01x03_Male | Connector:Conn_01x03_Male | Connector_PinHeader_2.54mm:PinHeader_1x03_P2.54mm_Vertical | ~
 |  | J6 | Conn_01x03_Male | Connector:Conn_01x03_Male | Connector_PinHeader_2.54mm:PinHeader_1x03_P2.54mm_Vertical | ~
 |  | J7 | Conn_01x03_Male | Connector:Conn_01x03_Male | Connector_PinHeader_2.54mm:PinHeader_1x03_P2.54mm_Vertical | ~
 |  | J8 | Conn_01x03_Male | Connector:Conn_01x03_Male | Connector_PinHeader_2.54mm:PinHeader_1x03_P2.54mm_Vertical | ~
 |  | J9 | Conn_01x02_Male | Connector:Conn_01x02_Male | Connector_PinHeader_2.54mm:PinHeader_1x02_P2.54mm_Vertical | ~
 |  | J10 | Conn_01x04_Female | Connector:Conn_01x04_Female | Connector_PinSocket_2.54mm:PinSocket_1x04_P2.54mm_Vertical | ~
 |  | Q1 | BC547 | Transistor_BJT:BC547 | Package_TO_SOT_THT:TO-92_Inline_Wide | http://www.fairchildsemi.com/ds/BC/BC547.pdf
 |  | Q2 | BC547 | Transistor_BJT:BC547 | Package_TO_SOT_THT:TO-92_Inline_Wide | http://www.fairchildsemi.com/ds/BC/BC547.pdf
 |  | Q3 | BC547 | Transistor_BJT:BC547 | Package_TO_SOT_THT:TO-92_Inline_Wide | http://www.fairchildsemi.com/ds/BC/BC547.pdf
 |  | Q4 | BC547 | Transistor_BJT:BC547 | Package_TO_SOT_THT:TO-92_Inline_Wide | http://www.fairchildsemi.com/ds/BC/BC547.pdf
 |  | R1 | R_PHOTO | Device:R_PHOTO | OptoDevice:R_LDR_5.0x4.1mm_P3mm_Vertical | ~
 |  | R2 | 10k | Device:R | Resistor_SMD:R_1206_3216Metric_Pad1.42x1.75mm_HandSolder | ~
 |  | R3 | 10k | Device:R | Resistor_SMD:R_1206_3216Metric_Pad1.42x1.75mm_HandSolder | ~
 |  | R4 | 10k | Device:R | Resistor_SMD:R_1206_3216Metric_Pad1.42x1.75mm_HandSolder | ~
 |  | R5 | 10k | Device:R | Resistor_SMD:R_1206_3216Metric_Pad1.42x1.75mm_HandSolder | ~
 |  | R6 | 22k | Device:R | Resistor_SMD:R_1206_3216Metric_Pad1.42x1.75mm_HandSolder | ~
 |  | R7 | 10k | Device:R | Resistor_SMD:R_1206_3216Metric_Pad1.42x1.75mm_HandSolder | ~
 |  | R8 | 10k | Device:R | Resistor_SMD:R_1206_3216Metric_Pad1.42x1.75mm_HandSolder | ~
 |  | R9 | 22k | Device:R | Resistor_SMD:R_1206_3216Metric_Pad1.42x1.75mm_HandSolder | ~
 |  | R10 | 22k | Device:R | Resistor_SMD:R_1206_3216Metric_Pad1.42x1.75mm_HandSolder | ~
 |  | R11 | 22k | Device:R | Resistor_SMD:R_1206_3216Metric_Pad1.42x1.75mm_HandSolder | ~
 |  | R12 | 51R | Device:R | Resistor_SMD:R_1206_3216Metric_Pad1.42x1.75mm_HandSolder | ~
 |  | R13 | 51R | Device:R | Resistor_SMD:R_1206_3216Metric_Pad1.42x1.75mm_HandSolder | ~
 |  | R14 | 51R | Device:R | Resistor_SMD:R_1206_3216Metric_Pad1.42x1.75mm_HandSolder | ~
 |  | R15 | 51R | Device:R | Resistor_SMD:R_1206_3216Metric_Pad1.42x1.75mm_HandSolder | ~
 |  | R16 | 1k | Device:R | Resistor_SMD:R_1206_3216Metric_Pad1.42x1.75mm_HandSolder | ~
 |  | R17 | 1k | Device:R | Resistor_SMD:R_1206_3216Metric_Pad1.42x1.75mm_HandSolder | ~
 |  | R18 | 330R | Device:R | Resistor_SMD:R_1206_3216Metric_Pad1.42x1.75mm_HandSolder | ~
 |  | R19 | 330R | Device:R | Resistor_SMD:R_1206_3216Metric_Pad1.42x1.75mm_HandSolder | ~
 |  | R20 | 4k7 | Device:R | Resistor_SMD:R_1206_3216Metric_Pad1.42x1.75mm_HandSolder | ~
 |  | R21 | 330R | Device:R | Resistor_SMD:R_1206_3216Metric_Pad1.42x1.75mm_HandSolder | ~
 |  | RV1 | R_POT | Device:R_POT | Potentiometer_THT:Potentiometer_Alps_RK09K_Single_Vertical | ~
 |  | SW1 | SW_Push | Switch:SW_Push | Button_Switch_THT:SW_PUSH_6mm_H13mm
 |  | SW2 | SW_Push | Switch:SW_Push | Button_Switch_THT:SW_PUSH_6mm_H13mm
 |  | U1 | DS18B20 | Sensor_Temperature:DS18B20 | Package_TO_SOT_THT:TO-92_Inline_Wide | http://datasheets.maximintegrated.com/en/ds/DS18B20.pdf
 |  | U2 | ESP32-DEVKITC-32D | ESP32-DEVKITC-32D:ESP32-DEVKITC-32D | ESP32-DEVKITC-32D:MODULE_ESP32-DEVKITC-32D | Eval Board For Esp-Wroom-32 | None | Espressif Systems | None | ESP32-DEVKITC-32D | Unavailable
 |  | U3 | PCA9685PW | Driver_LED:PCA9685PW | Package_SO:TSSOP-28_4.4x9.7mm_P0.65mm | http://www.nxp.com/documents/data_sheet/PCA9685.pdf
 |  | U4 | DHT11 | Sensor:DHT11 | Sensor:Aosong_DHT11_5.5x12.0_P2.54mm | http://akizukidenshi.com/download/ds/aosong/DHT11.pdf
Collated Components:
Item | Qty | Reference(s) | Value | LibPart | Footprint | Datasheet | Pole4 | Pole5 | Pole6 | Pole7 | Pole8
1 | 1 | BZ1 | Buzzer | Device:Buzzer | Buzzer_Beeper:Buzzer_12x9.5RM7.6 | ~
2 | 4 | C1, C2, C4, C6 | 220nF | Device:C | Capacitor_SMD:C_1206_3216Metric_Pad1.42x1.75mm_HandSolder | ~
3 | 2 | C3, C5 | 100uF | Device:CP | Capacitor_THT:CP_Radial_D6.3mm_P2.50mm | ~
4 | 1 | D1 | Nokia_5110_display | Nokia_5110:Nokia_5110_display | Nokia 5110 display:Nokia_5110_display
5 | 12 | D2, D3, D4, D5, D6, D7, D8, D9, D10, D11, D12, D13 | LED | Device:LED | LED_THT:LED_D3.0mm | ~
6 | 1 | D14 | LED_RCGB | Device:LED_RCGB | LED_THT:LED_D5.0mm-4_RGB_Wide_Pins | ~
7 | 1 | ENC1 | Rotary_Encoder_Switch | Device:Rotary_Encoder_Switch | Rotary_Encoder:RotaryEncoder_Alps_EC11E-Switch_Vertical_H20mm | ~
8 | 4 | H1, H2, H3, H4 | MountingHole | Mechanical:MountingHole | MountingHole:MountingHole_3.2mm_M3 | ~
9 | 1 | J1 | Conn_01x09_Female | Connector:Conn_01x09_Female | Connector_PinSocket_2.54mm:PinSocket_1x09_P2.54mm_Vertical | ~
10 | 7 | J2, J3, J4, J5, J6, J7, J8 | Conn_01x03_Male | Connector:Conn_01x03_Male | Connector_PinHeader_2.54mm:PinHeader_1x03_P2.54mm_Vertical | ~
11 | 1 | J9 | Conn_01x02_Male | Connector:Conn_01x02_Male | Connector_PinHeader_2.54mm:PinHeader_1x02_P2.54mm_Vertical | ~
12 | 1 | J10 | Conn_01x04_Female | Connector:Conn_01x04_Female | Connector_PinSocket_2.54mm:PinSocket_1x04_P2.54mm_Vertical | ~
13 | 4 | Q1, Q2, Q3, Q4 | BC547 | Transistor_BJT:BC547 | Package_TO_SOT_THT:TO-92_Inline_Wide | http://www.fairchildsemi.com/ds/BC/BC547.pdf
14 | 1 | R1 | R_PHOTO | Device:R_PHOTO | OptoDevice:R_LDR_5.0x4.1mm_P3mm_Vertical | ~
15 | 6 | R2, R3, R4, R5, R7, R8 | 10k | Device:R | Resistor_SMD:R_1206_3216Metric_Pad1.42x1.75mm_HandSolder | ~
16 | 4 | R6, R9, R10, R11 | 22k | Device:R | Resistor_SMD:R_1206_3216Metric_Pad1.42x1.75mm_HandSolder | ~
17 | 4 | R12, R13, R14, R15 | 51R | Device:R | Resistor_SMD:R_1206_3216Metric_Pad1.42x1.75mm_HandSolder | ~
18 | 2 | R16, R17 | 1k | Device:R | Resistor_SMD:R_1206_3216Metric_Pad1.42x1.75mm_HandSolder | ~
19 | 3 | R18, R19, R21 | 330R | Device:R | Resistor_SMD:R_1206_3216Metric_Pad1.42x1.75mm_HandSolder | ~
20 | 1 | R20 | 4k7 | Device:R | Resistor_SMD:R_1206_3216Metric_Pad1.42x1.75mm_HandSolder | ~
21 | 1 | RV1 | R_POT | Device:R_POT | Potentiometer_THT:Potentiometer_Alps_RK09K_Single_Vertical | ~
22 | 2 | SW1, SW2 | SW_Push | Switch:SW_Push | Button_Switch_THT:SW_PUSH_6mm_H13mm
23 | 1 | U1 | DS18B20 | Sensor_Temperature:DS18B20 | Package_TO_SOT_THT:TO-92_Inline_Wide | http://datasheets.maximintegrated.com/en/ds/DS18B20.pdf
24 | 1 | U2 | ESP32-DEVKITC-32D | ESP32-DEVKITC-32D:ESP32-DEVKITC-32D | ESP32-DEVKITC-32D:MODULE_ESP32-DEVKITC-32D | Eval Board For Esp-Wroom-32 | None | Espressif Systems | None | ESP32-DEVKITC-32D | Unavailable
25 | 1 | U3 | PCA9685PW | Driver_LED:PCA9685PW | Package_SO:TSSOP-28_4.4x9.7mm_P0.65mm | http://www.nxp.com/documents/data_sheet/PCA9685.pdf
26 | 1 | U4 | DHT11 | Sensor:DHT11 | Sensor:Aosong_DHT11_5.5x12.0_P2.54mm | http://akizukidenshi.com/download/ds/aosong/DHT11.pdf

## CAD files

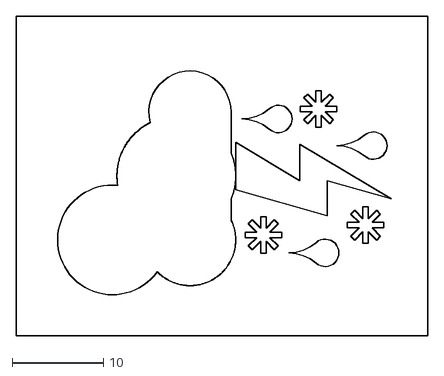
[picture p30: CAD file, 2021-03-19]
Electronics/ESP32 dev board/weather.dxf
45.0 x 35.0

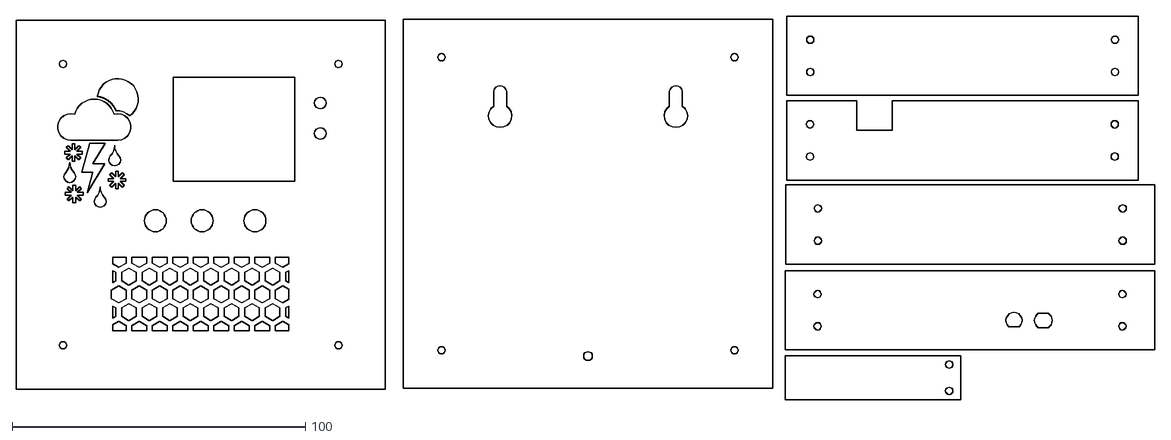
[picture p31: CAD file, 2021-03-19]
Electronics/ESP32 dev board/Cut.dxf
388.6 x 130.8

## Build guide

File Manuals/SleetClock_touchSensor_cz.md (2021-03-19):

V této kapitole je návod pro vybavení meteostanice SleetClock kapacitními senzory pro ovládání dotykem na dřevo.

# Obsah
* [Seznam součástek](#seznam)
* [Pájení konektoru dod PCB](#doPCB)
* [Příprava vodičů](#vodice)
* [Kapacitní plochy](#kapacity)
* [Kompletace](#komplet)

## <a name = "seznam">Seznam součástek</a>
+ 7 žilový kabel s konektorem
+ 7 cm měděné lepicí pásky šířky 6 mm

## <a name = "doPCB">Pájení konektoru do PCB</a>
1. Odšroubujte s 4 vruty z horní části krabičky s šestihrannou mřížkou.\
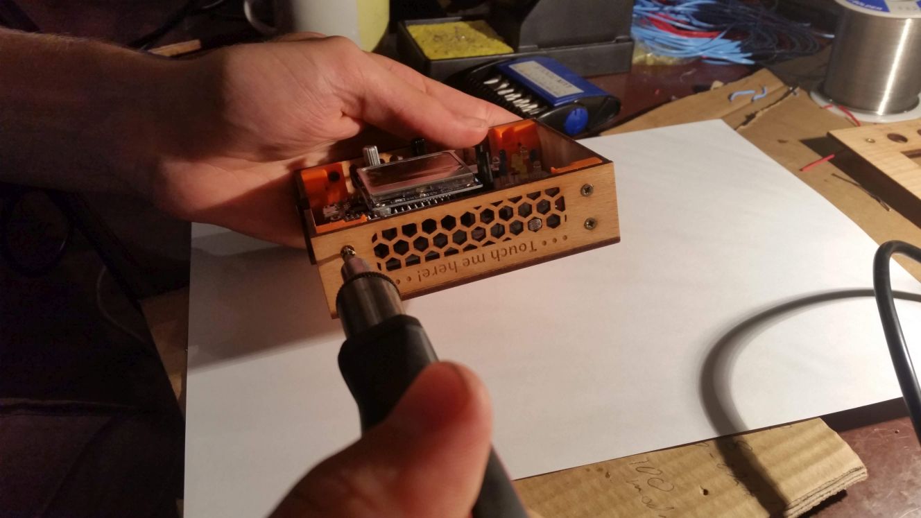
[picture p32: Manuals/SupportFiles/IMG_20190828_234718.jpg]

1. Odeberte horní část krabičky.\
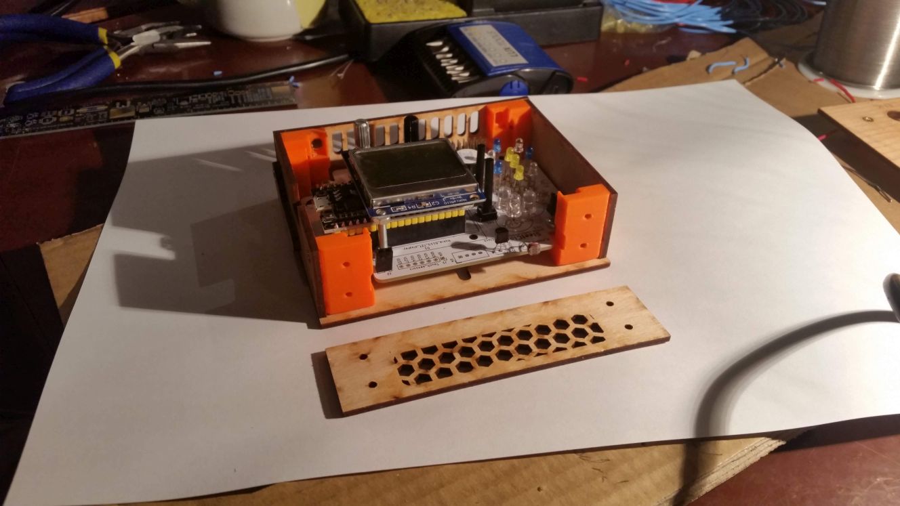
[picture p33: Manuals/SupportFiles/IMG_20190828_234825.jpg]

1. Vyjměte elektroniku a vložte do ní 7 pinový konektor podle obrázku. Pozor na orientaci konektoru.\
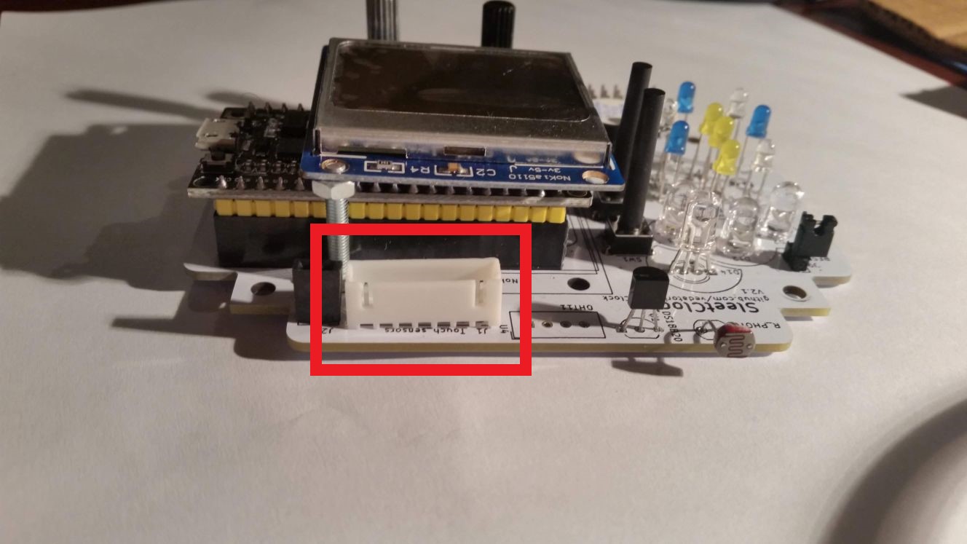
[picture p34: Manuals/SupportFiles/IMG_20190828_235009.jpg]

1. Zapájejte všech 7 pinů ze zadní strany PCB.\
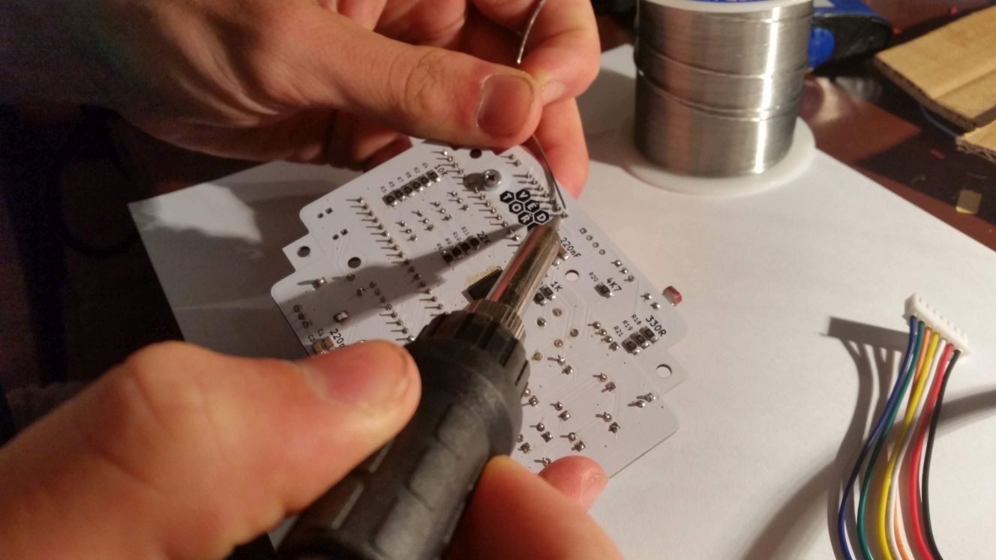
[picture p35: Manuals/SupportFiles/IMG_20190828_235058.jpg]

## <a name = "vodice">Připrava vodičů</a>
1. Štípacími kleštěmi ucvakněte 7 žilový kabel v délce 5 cm od konce konektoru.\
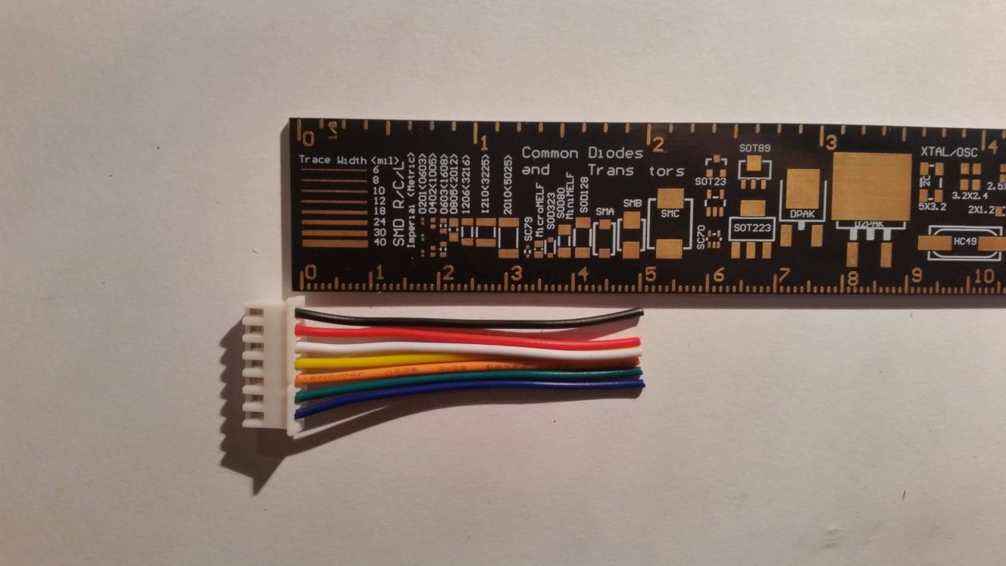
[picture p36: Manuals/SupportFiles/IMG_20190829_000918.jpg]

1. Nožem odizolujte konce vodičů v délce asi 3 mm.\
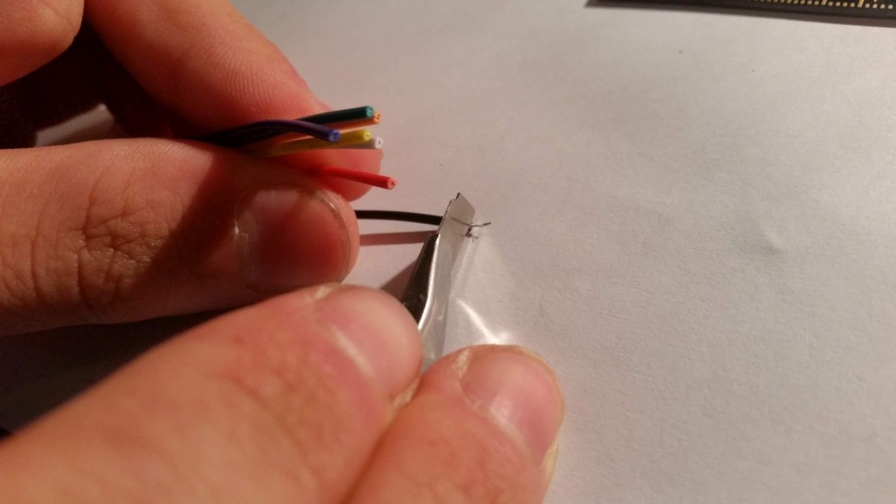
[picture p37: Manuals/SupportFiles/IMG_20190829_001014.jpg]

1. Ocínujte konce vodičů.\
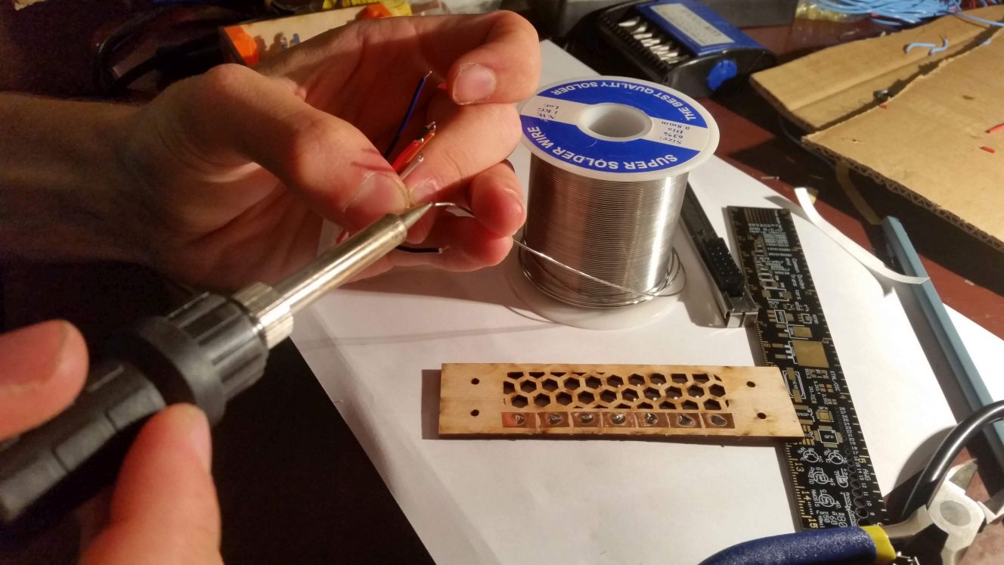
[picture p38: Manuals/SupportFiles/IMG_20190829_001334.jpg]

## <a name = "kapacity">Kapacitní plochy</a>
1. Nalepte 7 cm dlouhý kus měděné pásky do vnitřní strany horní desky krabičky. Měděný pásek musí být zarovnán s šestihrannou mřížkou.\
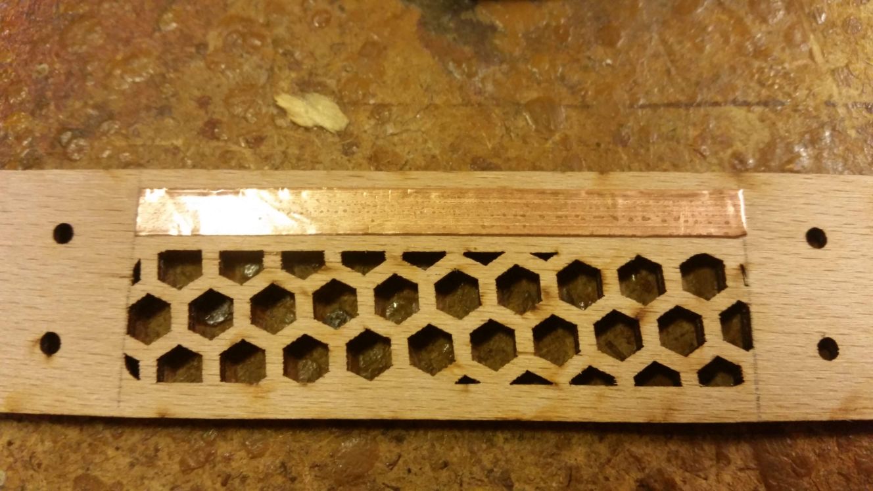
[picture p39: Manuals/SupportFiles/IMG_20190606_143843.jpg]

1. Ostrým předmětem naznačte do měděné pásky čáry ve vzdálenostech 1 cm.\
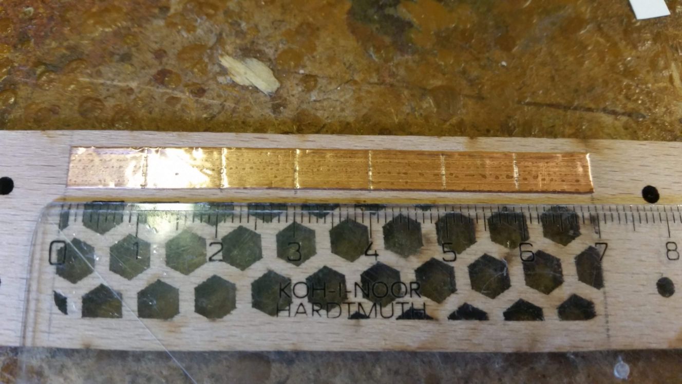
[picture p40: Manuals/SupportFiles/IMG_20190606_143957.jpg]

1. V naznačených čarách vyřízněte měď v šířce 1 mm tak, aby vzniklo 7 samostatných měděných kusů.\
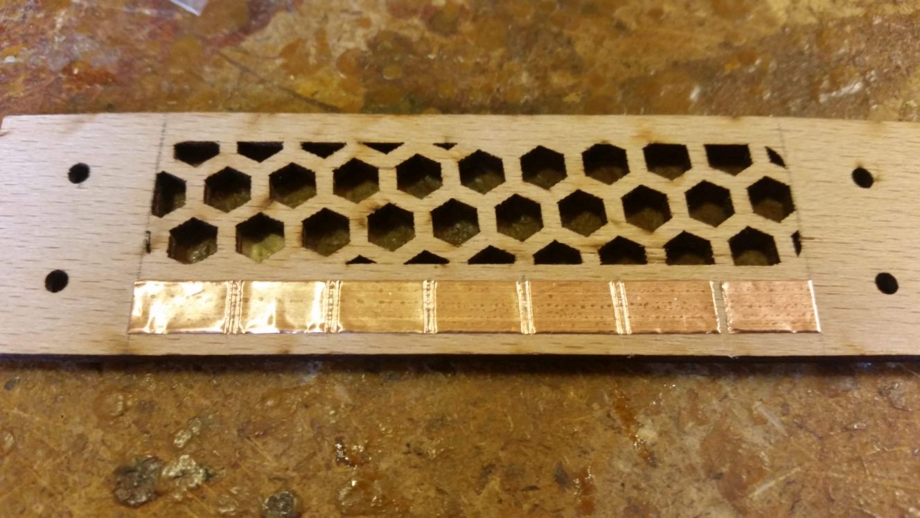
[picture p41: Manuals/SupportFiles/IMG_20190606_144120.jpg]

1. Pájkou ocínujte středy 7 měděných ploch.\
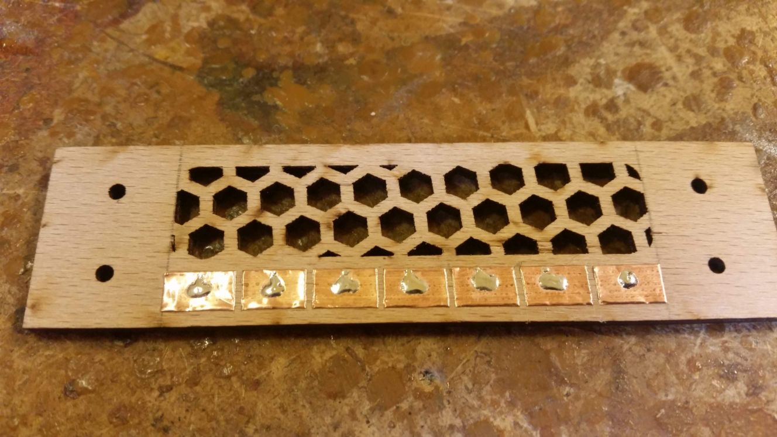
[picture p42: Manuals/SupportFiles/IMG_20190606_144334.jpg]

1. Připájejte všech 7 vodičů k měděným plochám přesně podle obrázku.
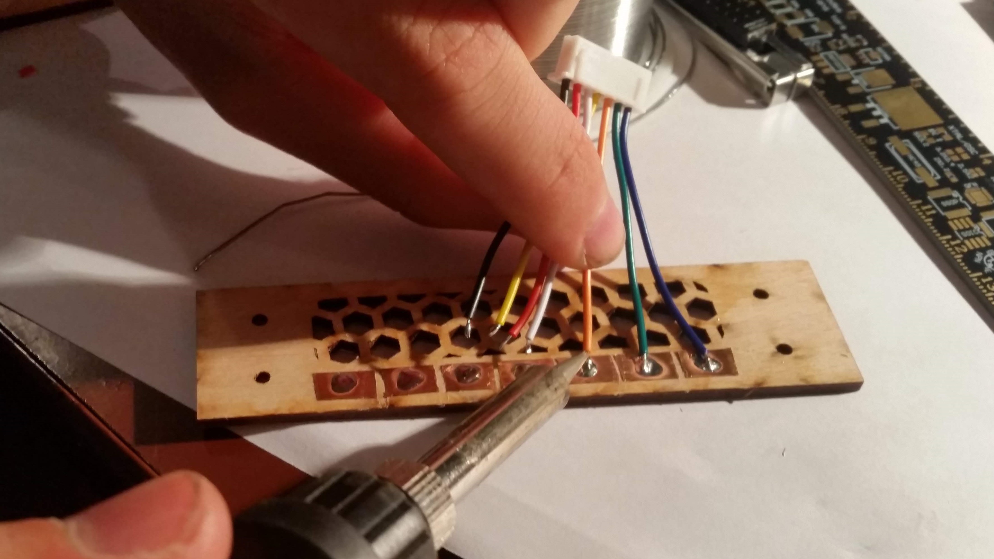
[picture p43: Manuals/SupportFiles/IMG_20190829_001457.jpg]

## <a name = "komplet">Kompletace</a>
1. Zapojte konektor s vodiči do PCB.\
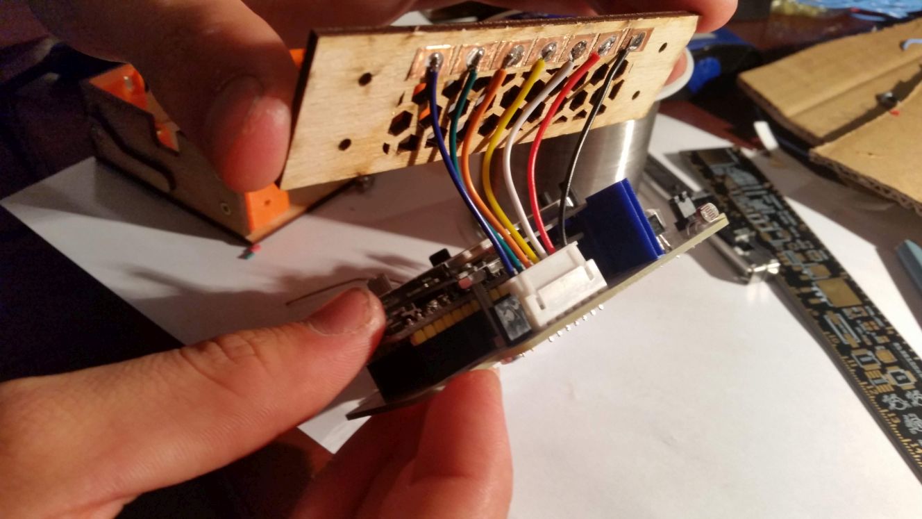
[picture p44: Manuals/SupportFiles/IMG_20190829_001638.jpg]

1. Přiložte horní stranu krabičky do původní polohy.\
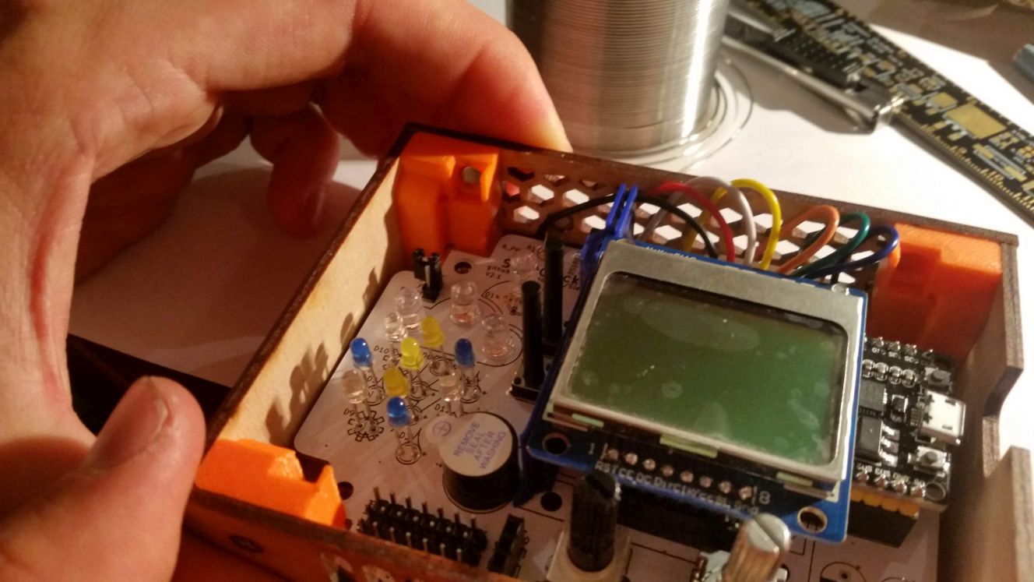
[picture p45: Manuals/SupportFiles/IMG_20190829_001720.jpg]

1. Zašroubujte zpět 4 vruty držící horní díl krabičky.\
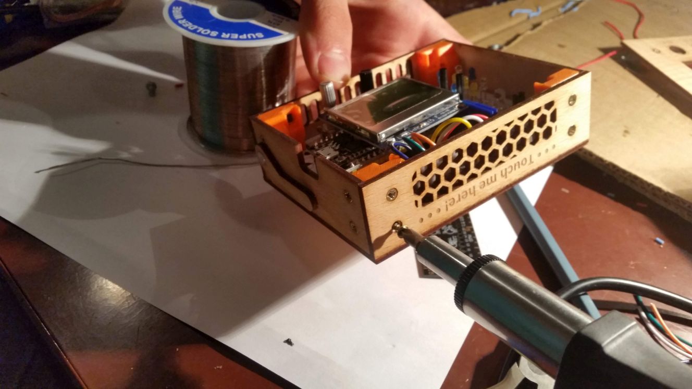
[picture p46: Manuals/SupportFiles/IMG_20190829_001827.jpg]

1. Uspořádejte vodiče dolů tak, aby nepřekážely tepelnému štítu.\
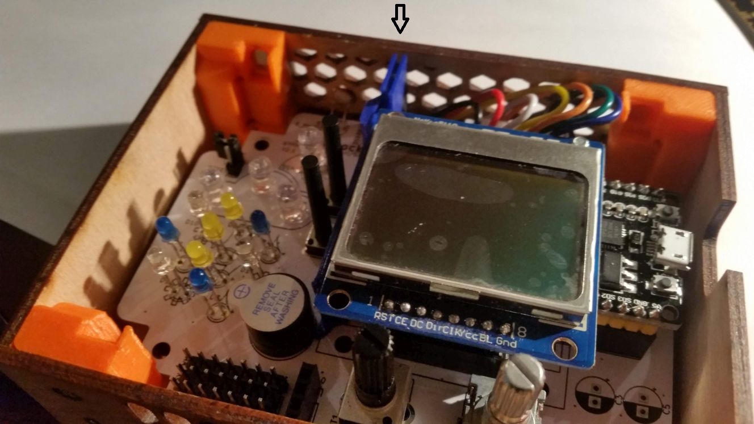
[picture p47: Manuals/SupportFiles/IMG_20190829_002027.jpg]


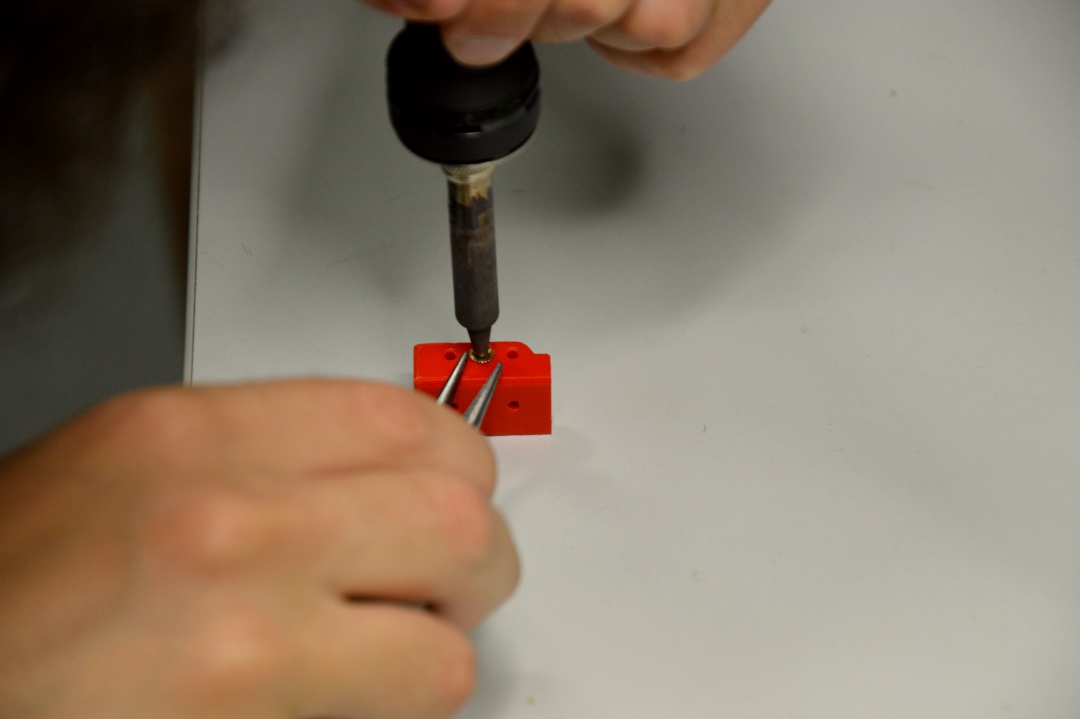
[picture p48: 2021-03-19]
Manuals/SupportFiles/007.jpg

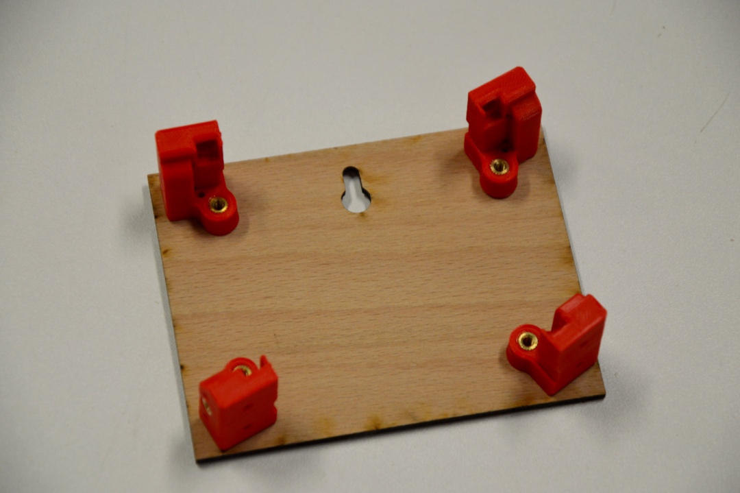
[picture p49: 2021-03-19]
Manuals/SupportFiles/012.jpg

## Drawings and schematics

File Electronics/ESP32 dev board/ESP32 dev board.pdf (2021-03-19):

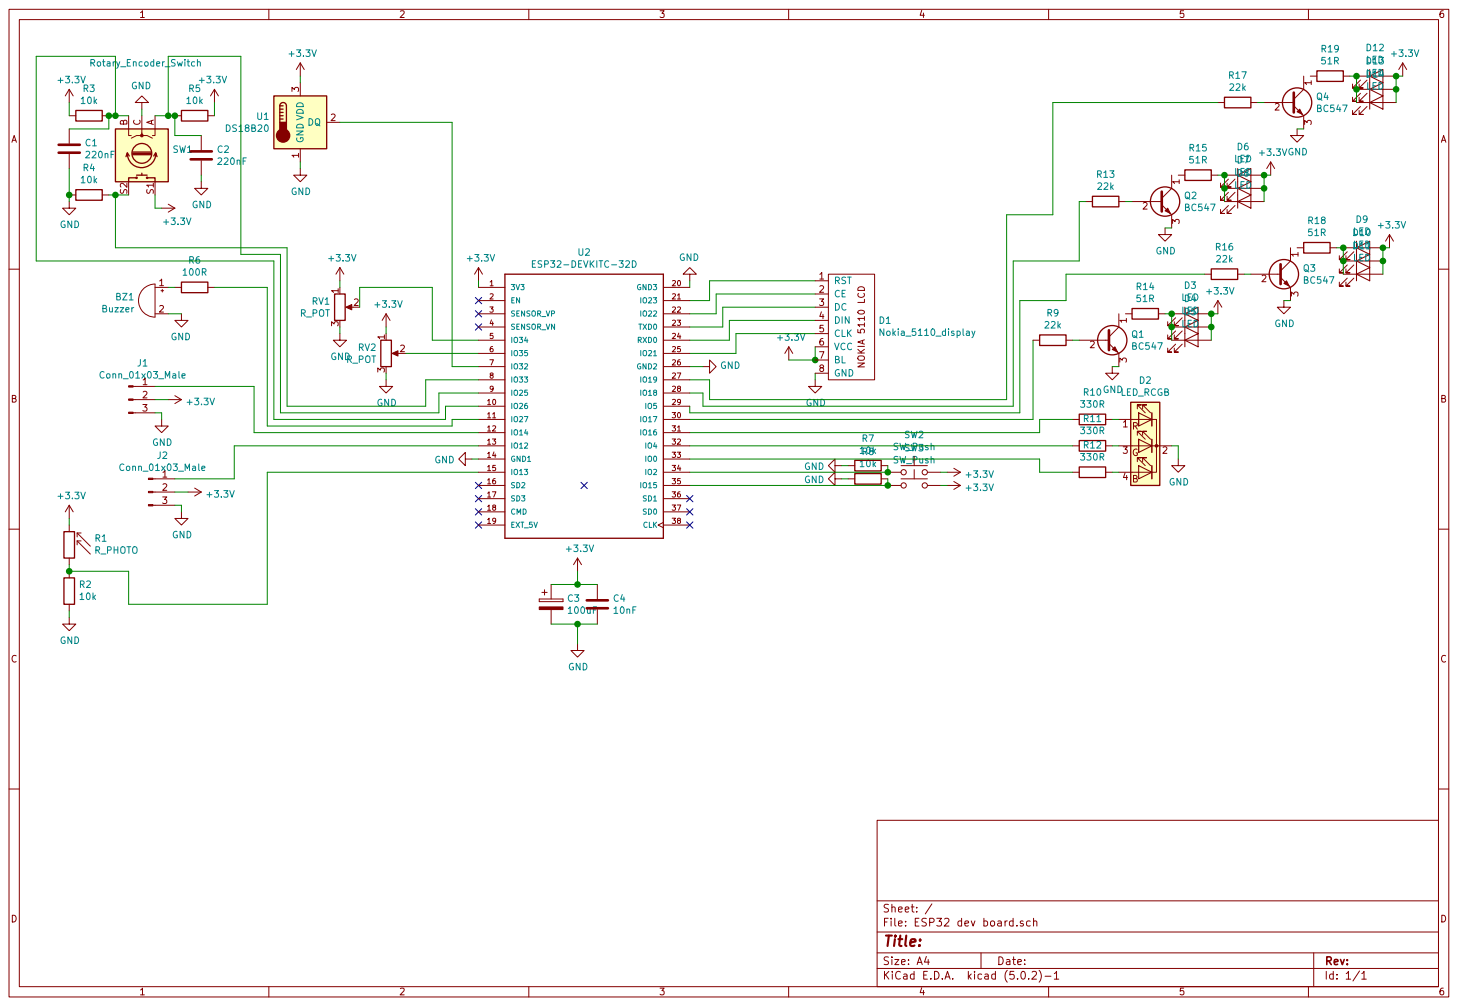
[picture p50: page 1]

Id: 1/1 Title: File: ESP32 dev board.sch Sheet: /

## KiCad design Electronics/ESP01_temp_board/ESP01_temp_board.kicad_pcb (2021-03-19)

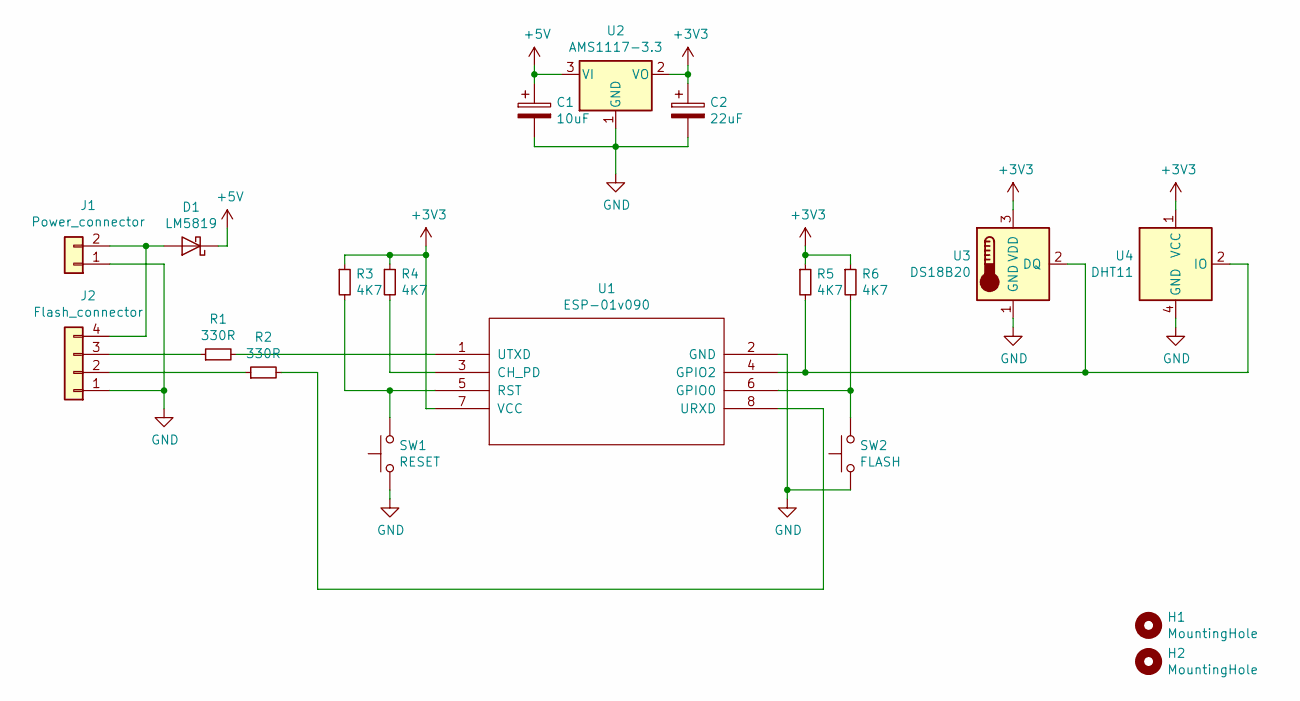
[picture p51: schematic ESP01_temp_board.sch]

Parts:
C1: 10uF; CP_Radial_D5.0mm_P2.00mm
C2: 22uF; CP_Radial_D5.0mm_P2.00mm
D1: LM5819; D_MiniMELF
H1, H2: MountingHole; MountingHole_3.2mm_M3
J1: Power_connector; TerminalBlock_bornier-2_P5.08mm
J2: Flash_connector; PinSocket_1x04_P2.54mm_Vertical
R1, R2: 330R; R_1206_3216Metric_Pad1.42x1.75mm_HandSolder
R3, R4, R5, R6: 4K7; R_1206_3216Metric_Pad1.42x1.75mm_HandSolder
SW1: RESET; SW_PUSH_6mm
SW2: FLASH; SW_PUSH_6mm
U1: ESP-01v090; ESP-01
U2: AMS1117-3.3; SOT-223-3_TabPin2
U3: DS18B20; TO-92_Inline_Wide
U4: DHT11; Aosong_DHT11_5.5x12.0_P2.54mm

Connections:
+3V3: C2.1, R3.1, R4.1, R5.1, R6.1, U1.7 (VCC), U2.2 (VO), U3.3 (VDD), U4.1 (VCC)
+5V: C1.1, D1.1 (K), U2.3 (VI)
GND: C1.2, C2.2, J1.1, J2.1, SW1.1, SW2.1, U1.2 (GND), U2.1 (GND), U3.1 (GND), U4.4 (GND)
unnamed: D1.2 (A), J1.2, J2.4
unnamed: J2.2, R2.1
unnamed: J2.3, R1.1
unnamed: R1.2, U1.1 (UTXD)
unnamed: R2.2, U1.8 (URXD)
unnamed: R3.2, SW1.2, U1.5 (RST)
unnamed: R4.2, U1.3 (CH_PD)
unnamed: R5.2, U1.4 (GPIO2), U3.2 (DQ), U4.2 (IO)
unnamed: R6.2, SW2.2, U1.6 (GPIO0)

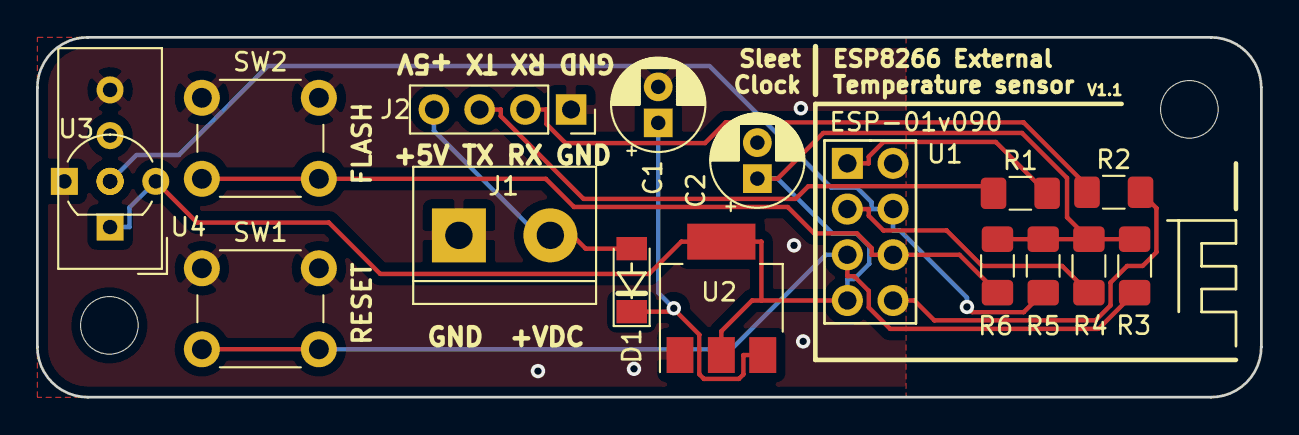
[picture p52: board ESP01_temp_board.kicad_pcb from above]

Board: 2 copper layers, 68.0 x 20.0 mm, 20 parts (1 on the bottom side), 12 nets.

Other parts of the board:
.: .; Vedatori_18mm

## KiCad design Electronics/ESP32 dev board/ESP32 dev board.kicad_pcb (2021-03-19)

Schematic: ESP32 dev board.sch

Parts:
C1, C2, C4, C6: 220nF; C_1206_3216Metric_Pad1.42x1.75mm_HandSolder
C3, C5: 100uF; CP_Radial_D6.3mm_P2.50mm
D1: Nokia_5110_TZT_display
ENC1: Rotary_Encoder_Switch; RotaryEncoder_Alps_EC11E-Switch_Vertical_H20mm
H1, H2, H3, H4: MountingHole; MountingHole_3.2mm_M3
J1: Touch_sensors; PinSocket_1x07_P2.54mm_Vertical
J2: Conn_01x02_Female; PinSocket_1x02_P2.54mm_Vertical
J9: RESET; PinHeader_1x02_P2.54mm_Vertical
J10: ESP-01_program; PinSocket_1x04_P2.54mm_Vertical
POT1: R_POT; Potentiometer_Alps_RK09K_Single_Vertical
R1: R_PHOTO; R_LDR_5.0x4.1mm_P3mm_Vertical
R2, R3, R4, R5, R7, R8: 10k; R_1206_3216Metric_Pad1.42x1.75mm_HandSolder
R20: 4k7; R_1206_3216Metric_Pad1.42x1.75mm_HandSolder
SW1, SW2: SW_Push; SW_PUSH_6mm_H13mm
U1: DS18B20; TO-92_Inline_Wide
U2: ESP32-DEVKITC-32D; MODULE_ESP32-DEVKITC-32D
U4: DHT11; Aosong_DHT11_5.5x12.0_P2.54mm

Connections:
+3V3: C3.1, C4.1, D1.6, ENC1.S1, POT1.1, R1.2, R3.2, R5.2, R20.2, SW1.2, SW2.2, U1.3 (VDD), U2.1 (3V3), U4.1 (VCC); also elsewhere on the board
+5V: C5.1, C6.1, J10.1, U2.19 (EXT_5V); also elsewhere on the board
BL: D1.7; also elsewhere on the board
CE: D1.2, U2.29 (IO5)
CLK: D1.5, U2.21 (IO23)
DC: D1.3, U2.28 (IO18)
DIN: D1.4, U2.27 (IO19)
EN: J9.2, U2.2 (EN)
GND: C1.2, C2.2, C3.2, C4.2, C5.2, C6.2, D1.8, ENC1.C, J9.1, J10.4, POT1.3, R2.1, R4.2, R7.2, R8.2, U1.1 (GND), U2.14 (GND1), U2.20 (GND3), U2.26 (GND2), U4.4 (GND); also elsewhere on the board
RST: D1.1, U2.7 (IO32)
RX: J10.2, U2.24 (RXD0)
SCL: U2.22 (IO22); also elsewhere on the board
SDA: U2.25 (IO21); also elsewhere on the board
TX: J10.3, U2.23 (TXD0)
button0: R7.1, SW1.1, U2.3 (SENSOR_VP)
button1: R8.1, SW2.1, U2.4 (SENSOR_VN)
encoderA: C1.1, ENC1.B, R3.1, U2.9 (IO25)
encoderB: C2.1, ENC1.A, R5.1, U2.10 (IO26)
encoderSwitch: ENC1.S2, R4.1, U2.30 (IO17)
photoresistor: R1.1, R2.2, U2.6 (IO35)
potentiometer: POT1.2, U2.5 (IO34)
tempData: R20.1, U1.2 (DQ), U2.31 (IO16), U4.2 (IO)
touch0: J1.1, U2.32 (IO4)
touch1: J2.1, U2.33 (IO0)
touch2: J2.2, U2.34 (IO2)
touch3: J1.2, U2.35 (IO15)
touch4: J1.3, U2.15 (IO13)
touch5: J1.4, U2.13 (IO12)
touch6: J1.5, U2.12 (IO14)
touch7: J1.6, U2.11 (IO27)
touch8: J1.7, U2.8 (IO33)

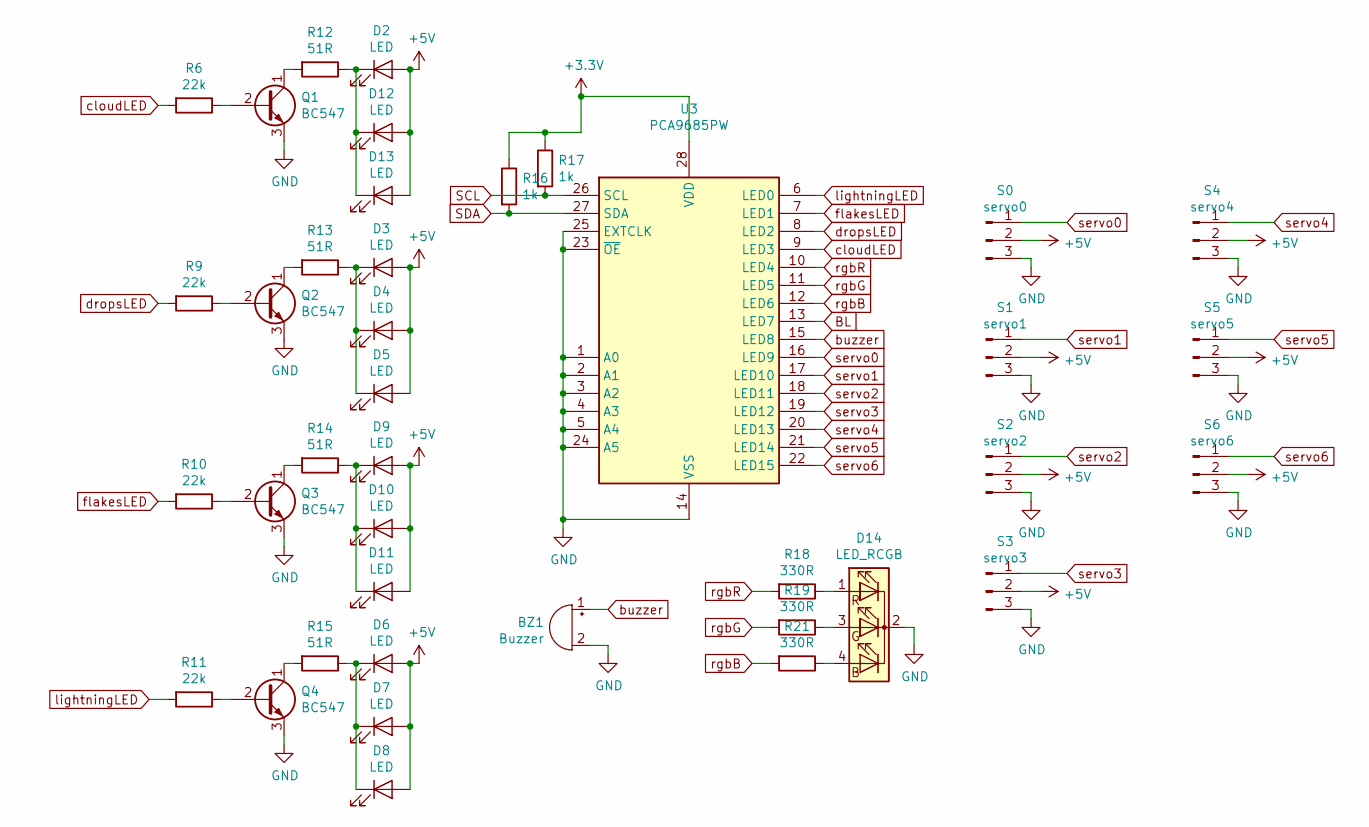
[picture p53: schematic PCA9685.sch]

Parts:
BZ1: Buzzer; Buzzer_12x9.5RM7.6
D2, D3, D4, D5, D6, D7, D8, D9, D10, D11, D12, D13: LED; LED_D3.0mm
D14: LED_RCGB; LED_D5.0mm-4_RGB_Wide_Pins
Q1, Q2, Q3, Q4: BC547; TO-92_Inline_Wide
R6, R9, R10, R11: 22k; R_1206_3216Metric_Pad1.42x1.75mm_HandSolder
R12, R13, R14, R15: 51R; R_1206_3216Metric_Pad1.42x1.75mm_HandSolder
R16, R17: 1k; R_1206_3216Metric_Pad1.42x1.75mm_HandSolder
R18, R19, R21: 330R; R_1206_3216Metric_Pad1.42x1.75mm_HandSolder
S0: servo0; PinHeader_1x03_P2.54mm_Vertical
S1: servo1; PinHeader_1x03_P2.54mm_Vertical
S2: servo2; PinHeader_1x03_P2.54mm_Vertical
S3: servo3; PinHeader_1x03_P2.54mm_Vertical
S4: servo4; PinHeader_1x03_P2.54mm_Vertical
S5: servo5; PinHeader_1x03_P2.54mm_Vertical
S6: servo6; PinHeader_1x03_P2.54mm_Vertical
U3: PCA9685PW; TSSOP-28_4.4x9.7mm_P0.65mm

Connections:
+3V3: R16.1, R17.1, U3.28 (VDD); also elsewhere on the board
+5V: D2.2 (A), D3.2 (A), D4.2 (A), D5.2 (A), D6.2 (A), D7.2 (A), D8.2 (A), D9.2 (A), D10.2 (A), D11.2 (A), D12.2 (A), D13.2 (A), S0.2, S1.2, S2.2, S3.2, S4.2, S5.2, S6.2; also elsewhere on the board
BL: U3.13 (LED7); also elsewhere on the board
GND: BZ1.2 (+), D14.2 (K), Q1.3 (E), Q2.3 (E), Q3.3 (E), Q4.3 (E), S0.3, S1.3, S2.3, S3.3, S4.3, S5.3, S6.3, U3.1 (A0), U3.2 (A1), U3.3 (A2), U3.4 (A3), U3.5 (A4), U3.14 (VSS), U3.23 (~OE), U3.24 (A5), U3.25 (EXTCLK); also elsewhere on the board
unnamed: D3.1 (K), D4.1 (K), D5.1 (K), R13.1
unnamed: D6.1 (K), D7.1 (K), D8.1 (K), R15.1
unnamed: D9.1 (K), D10.1 (K), D11.1 (K), R14.1
unnamed: D2.1 (K), D12.1 (K), D13.1 (K), R12.1
unnamed: D14.1 (RA), R18.1
unnamed: D14.3 (GA), R19.1
unnamed: D14.4 (BA), R21.1
unnamed: Q1.1 (C), R12.2
unnamed: Q1.2 (B), R6.1
unnamed: Q2.1 (C), R13.2
unnamed: Q2.2 (B), R9.1
unnamed: Q3.1 (C), R14.2
unnamed: Q3.2 (B), R10.1
unnamed: Q4.1 (C), R15.2
unnamed: Q4.2 (B), R11.1
SCL: R17.2, U3.26 (SCL); also elsewhere on the board
SDA: R16.2, U3.27 (SDA); also elsewhere on the board
buzzer: BZ1.1 (-), U3.15 (LED8)
cloudLED: R6.2, U3.9 (LED3)
dropsLED: R9.2, U3.8 (LED2)
flakesLED: R10.2, U3.7 (LED1)
lightningLED: R11.2, U3.6 (LED0)
rgbB: R21.2, U3.12 (LED6)
rgbG: R19.2, U3.11 (LED5)
rgbR: R18.2, U3.10 (LED4)
servo0: S0.1, U3.16 (LED9)
servo1: S1.1, U3.17 (LED10)
servo2: S2.1, U3.18 (LED11)
servo3: S3.1, U3.19 (LED12)
servo4: S4.1, U3.20 (LED13)
servo5: S5.1, U3.21 (LED14)
servo6: S6.1, U3.22 (LED15)

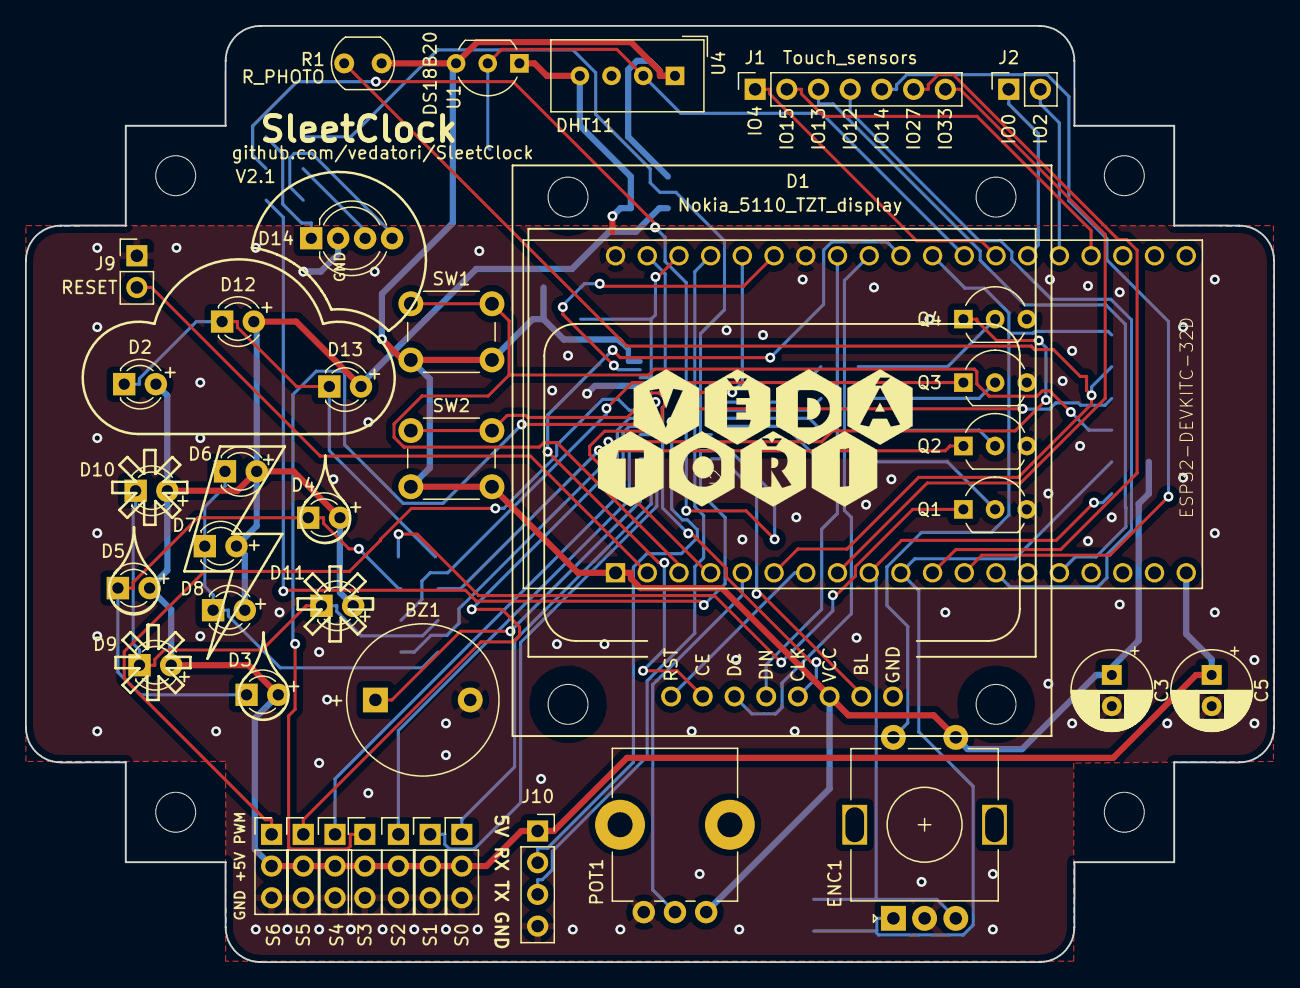
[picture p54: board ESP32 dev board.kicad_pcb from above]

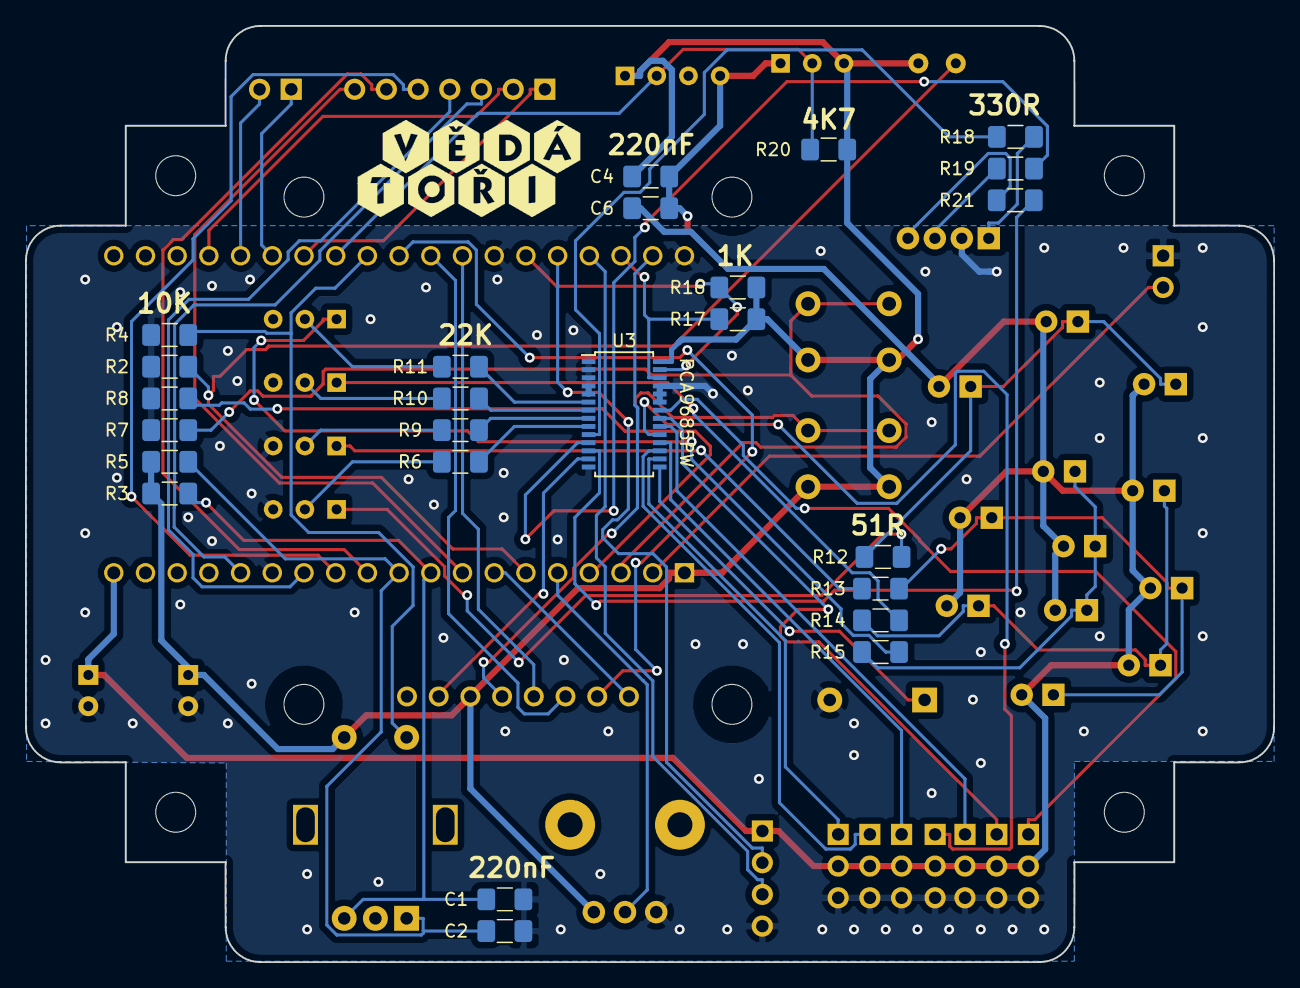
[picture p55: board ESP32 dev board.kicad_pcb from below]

Board: 2 copper layers, 100.0 x 75.0 mm, 70 parts (26 on the bottom side), 61 nets.

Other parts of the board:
.: .; Vedatori_18mm

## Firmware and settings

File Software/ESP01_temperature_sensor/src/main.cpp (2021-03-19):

#include <Arduino.h>
#include <OneWire.h>
#include <DallasTemperature.h>
#include <ESP8266WiFi.h>
#include <DNSServer.h>
#include <ESP8266WebServer.h>
#include <WiFiManager.h>         //https://github.com/tzapu/WiFiManager

#include <WiFiUDP.h>

unsigned int localPort = 12345;      // local port to listen for UDP packets
WiFiUDP Udp;
IPAddress remoteIP(192,168,0,19);

const int pinCidlaDS = 2;
OneWire oneWireDS(pinCidlaDS);
DallasTemperature dallasTemp(&oneWireDS);
float filteredTemp =  20.0;
float inputTemp = 0.0;

WiFiManager wifiManager;

void setup(void) {
    Serial.begin(115200);
    dallasTemp.begin();

    //wifi_set_sleep_type(LIGHT_SLEEP_T);

    //Udp.begin(localPort);
}

void loop(void) {
    wifiManager.autoConnect("ESP01_temp_sensor");
    Serial.println(WiFi.localIP());

    dallasTemp.requestTemperatures();
    inputTemp = dallasTemp.getTempCByIndex(0) - 3.7;
    if(inputTemp > 0 && inputTemp < 50)
        filteredTemp = /*0.9*filteredTemp + 0.1**/inputTemp;
    char buffer[50];
    sprintf (buffer, "%.2f", filteredTemp);

    Serial.println(buffer);

    //Udp.beginPacket(Udp.remoteIP(), Udp.remotePort());
    Udp.beginPacket(remoteIP, 56841);
    Udp.write(buffer);
    Udp.endPacket();
    delay(500);     //necessary for packet transmission before forceSleep
    WiFi.forceSleepBegin(); //Modem sleep, ca. 17 mA consumption
    delay(10000);
    WiFi.forceSleepWake();
}
